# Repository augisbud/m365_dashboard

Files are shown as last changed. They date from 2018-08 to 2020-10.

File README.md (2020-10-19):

# Xiaomi M365 Display [This project is no longer maintained, because I don't have a platform to test it.]

I will be pushing pull requests, if you improve this in any way possible feel free to create a push request.



# Products Used  
Arduino Pro Mini    
I2C OLED 0.96" or 1.3" Screen
FTD1232 Usb Programmer   
3d Printed Bracket  
1N4148 Diode  
0.25w 120ohm Resistor       

Estimated price is around 20$ (Inluding Printed Parts).

Knowing the price is around 20$ you can get the Xiaomi M365 Pro top panel from aliexpress for around the same price and a better look, unless you need additional features just go for the pro display.

# Flashing  
  
Please install the libraries I provided in the files, install them to you arduino library folder, usually              
  C:\Users\\%username%\Documents\Arduino\libraries  
I'd recommend you to use Arduino 1.6.6  
https://www.arduino.cc/en/Main/OldSoftwareReleases  

# Physical Connections  
  

# Updating M365 firmware / Disabling the Dashboard
Turn on the scooter and immediately engage and hold the throttle and brake before the logo disappears from the dashboard LCD. You will enter on dashboard disabled mode.
The Arduino TX/RX pins will go to hi impedance state leaving the communication BUS free.

By this way you can update de M365 firmware without disconnecting the dashboard or any cable.

A new power cycle will reset the dashboard to normal mode.

# Known Issues  
Sometimes the Arduino Freezes, a watchdog is in place but doesn't always trigger.  

# Screen caps
# Soldering, soldered directly to the cable coming from the MCU
5V To Red    
GND To Black  
BUS To Yellow  
  
A video on how everything is soldered may come soon.

Meanwhile you can enable subtitles in English in this YouTube video produced in Spanish language
https://www.youtube.com/watch?v=JQUNXCyj2Fs

# UI
UI pictures from version 0.2  
  
  

More pictures are coming soon.

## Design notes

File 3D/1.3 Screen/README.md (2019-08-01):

This is some CAD files for the 1.3" screen insted of the 0.96" one.

# Note:
You need to cut off one side where you put in the actual screen to fit it in

I haven't had time to fix this but feel free to DIY!

The 1.3" screen seems like it not SSD and so has a white line on the left and some letters can be consmed by the left side like [this](https://i.imgur.com/5XdflrQ.jpg) so I've added a language.h filt that *kinda* works but still kinda jank.

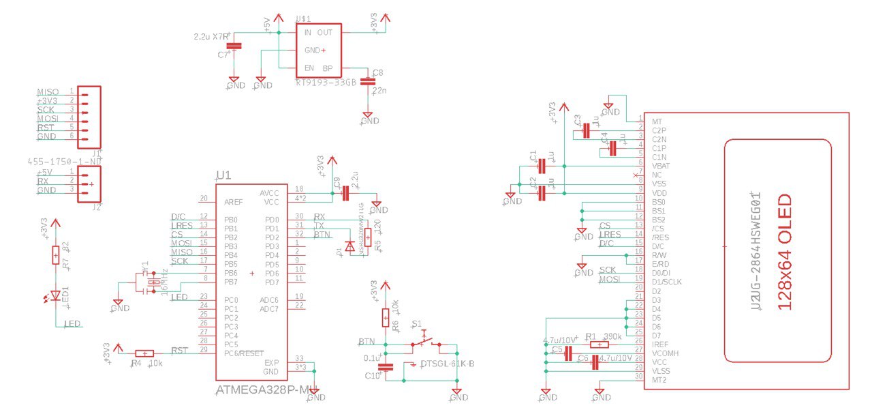
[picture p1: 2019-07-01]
circuit/v1_working.png

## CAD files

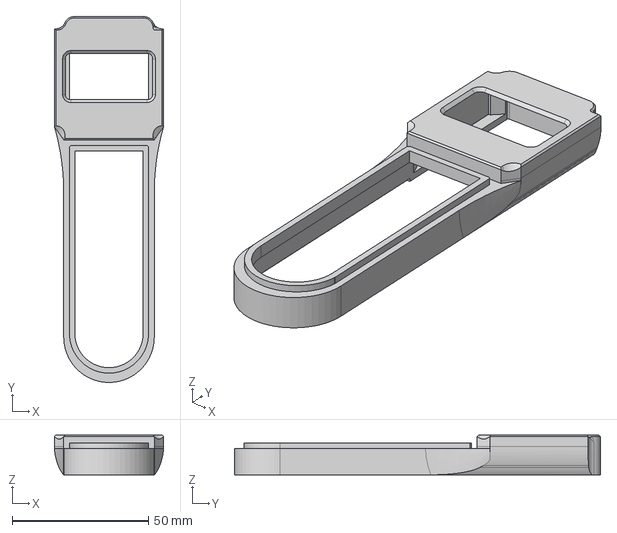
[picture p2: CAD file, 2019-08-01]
3D/1.3 Screen/case_v4_1.3-screen.step
40.0 x 134.1 x 14.6 mm

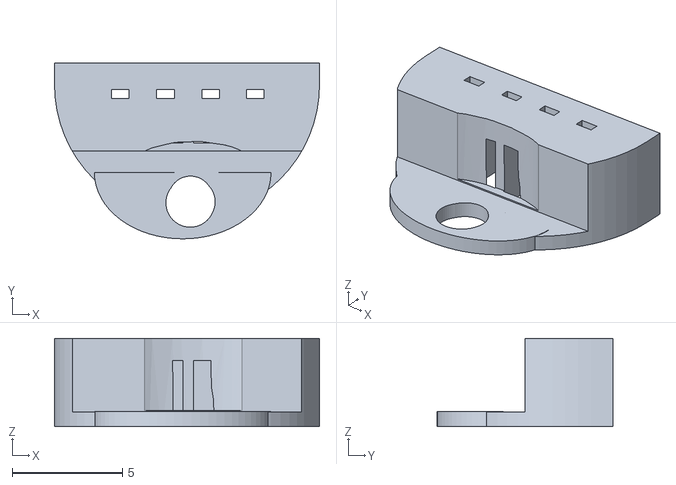
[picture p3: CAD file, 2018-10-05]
3D/Connector-edited.stl
12.0 x 7.96 x 4.00

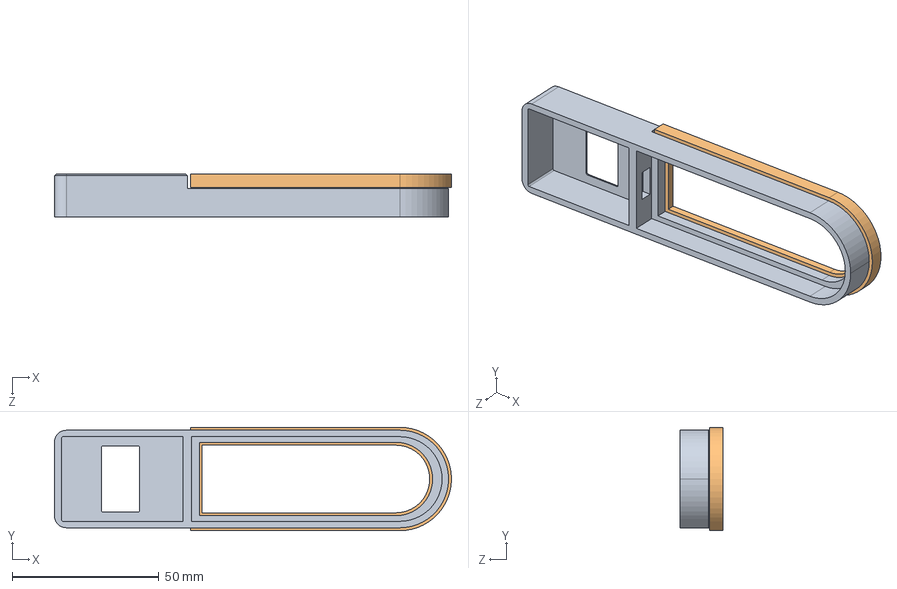
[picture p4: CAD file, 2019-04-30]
3D/newCase/STEP/case_v3.STEP
135.1 x 35.2 x 14.6 mm

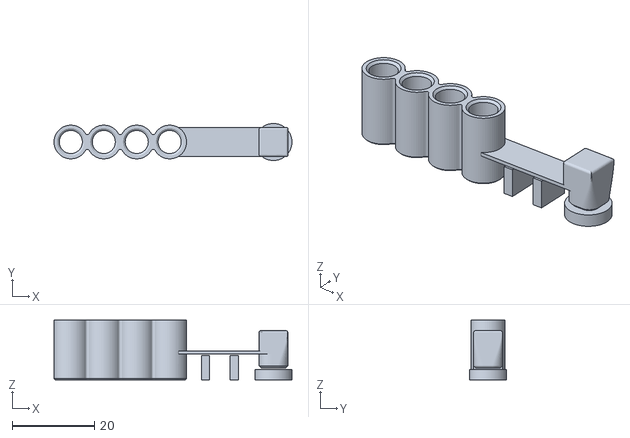
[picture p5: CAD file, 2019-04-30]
3D/newCase/STL/leds_v3_selfSupported.STL
57.8 x 9.00 x 14.4

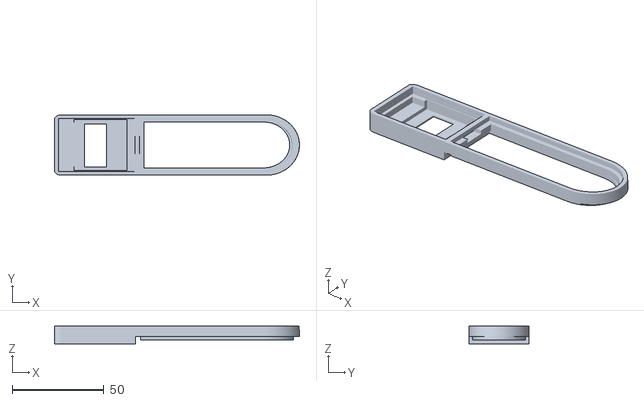
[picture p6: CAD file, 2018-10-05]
3D/Bracket-edited.stl
133.7 x 33.0 x 9.65

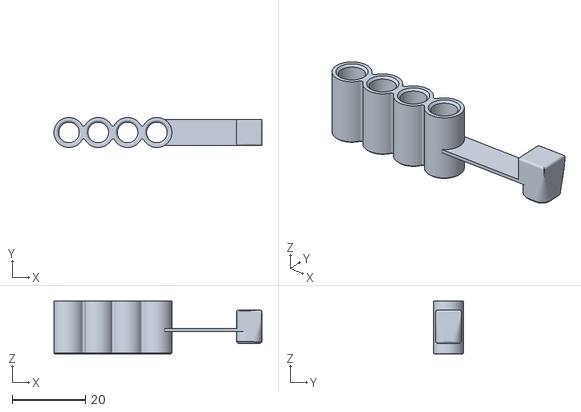
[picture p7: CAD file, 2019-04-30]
3D/newCase/STL/leds_v3_noSupports.STL
56.8 x 8.19 x 14.4

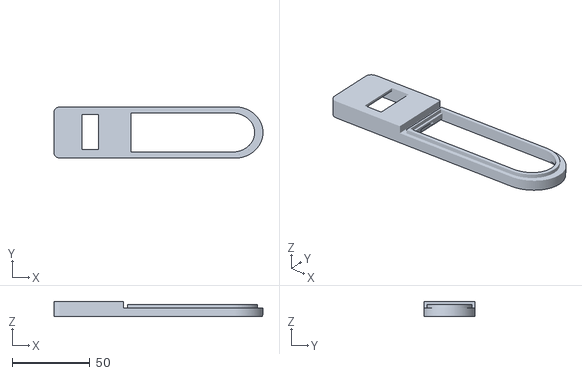
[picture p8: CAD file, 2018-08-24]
3D/Bracket.stl
134.1 x 33.0 x 9.64

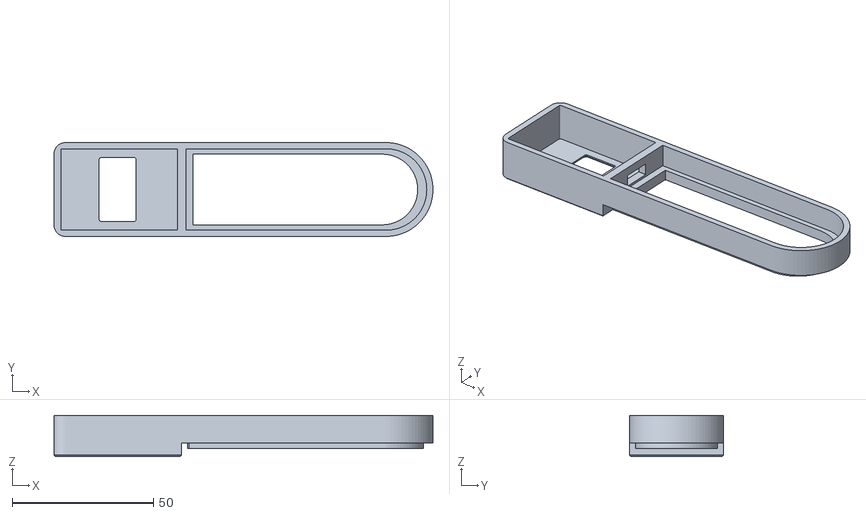
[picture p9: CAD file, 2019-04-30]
3D/newCase/STL/case_v3_noSupports.STL
134.1 x 33.2 x 14.6

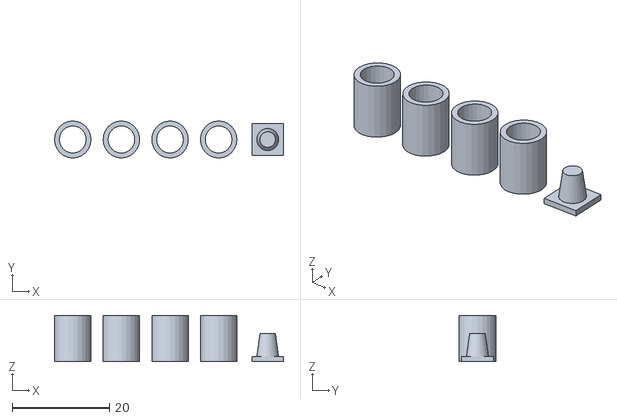
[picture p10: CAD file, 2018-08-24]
3D/LEDS & Button Extender.stl
47.1 x 7.63 x 9.50

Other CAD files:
3D/newCase/STEP/leds_v3.STEP
3D/newCase/STL/case_v3_selfSupported.STL
3D/1.3 Screen/case_v4_1.3-screen.f3d
3D/1.3 Screen/case_v4_1.3-screen.stl
3D/Custom top panel.f3d
3D/M365_panel_windowed.f3d
3D/newCase/SLDPRT/case_v3.SLDPRT
3D/newCase/SLDPRT/leds_v3.SLDPRT

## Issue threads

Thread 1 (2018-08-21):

Hello Kate - no Bus-

McKaNaN, 2018-08-21:
Hi.

I installed it and all done! :)

The problem, when I power on M365: LCD shows this message: "Hello Kate - no Bus -"
Any idea?

McKaNaN, 2018-08-21:
https://youtu.be/q8CMcGD0eyE

augisbud, 2018-08-24:
Have you used the schematics provided?
https://camo.githubusercontent.com/a912641249173768ae60670e843c62294d06da4f/68747470733a2f2f656c656374726f2e636c75622f646174612f666f72756d2f6d657373616765732f3432363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

augisbud, 2018-08-24:
Gonna upload an updated version :)

augisbud, 2018-08-24:
Check out the new code provided, it's a revision from the original one, better ui and stability, however the arduino freezes once in a while, a watchdog seems to help it but not all the time, still looking for a solution 😕

McKaNaN, 2018-08-24:
Ok! I check it and comment here :)

McKaNaN, 2018-08-27:
I compiled new code and show this:

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

A friend say me that the connection is:
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

Its correct?

augisbud, 2018-08-27:
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

augisbud, 2018-08-27:
I use this exact scheme without a problem

augisbud, 2018-08-27:
Send me a picture of the top part of your scooter with the pcb

McKaNaN, 2018-08-27:
Nothing. I cant connect BUS with screen.
All time shows same message: "BUS not connected! No data to display!"

I have question:
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

This pins are correct?

augisbud, 2018-08-27:
Yes the pins are correct, can you unscrew the pcb and send me a pic

McKaNaN, 2018-08-27:
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

Connections are same at schematics :)

augisbud, 2018-08-27:
I meant the scooter's pcb

augisbud, 2018-08-27:
The blue one with the button

augisbud, 2018-08-27:
Ok, I'm going to flash the firmware to my scooter to make sure it's ok

McKaNaN, 2018-08-27:
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

I used this connection picture. I think that is the same that you but I cant understand where is the problem :(

augisbud, 2018-08-27:
Me neither, are those really 1n4148 diode, 120 resistor?

McKaNaN, 2018-08-27:
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
This is the resistor

Diode shows:
PH
41
48

Is correct?

augisbud, 2018-08-27:
You might wanna try a 1n4148 diode although they seem to be very similar

McKaNaN, 2018-08-27:
I dont know....
I need to go to buy new diode.
I change + and - of diode, and shows same message :(

OMG

chriskross, 2018-09-01:
Have you connect the same gnd for arduino and pcb?

McKaNaN, 2018-09-01:
Yes! The GND of Bluetooth PCB in GND of Arduino Mini Pro

Closed 2018-09-14.

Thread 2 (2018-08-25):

M365 languages translation

AntoineWaes, 2018-08-25:
Hey ! I can provide you my language.h file in French if you want to add it to the files ;)
Maybe you could do a video showing how to plug and solder the wires

Thanks for the sharing, and nice work dude !

AntoineWaes, 2018-08-25:
Thanks a lot for the screens ! The wiring doesn't seems to work for me, it keeps saying 'No bus connected" .. And the M365 shows the 4 LEDS on (with one green)...

augisbud, 2018-08-25:
Have you connected the resistors and the diode
?

AntoineWaes, 2018-08-25:
Yes, this is what I did, is it OK ?
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

augisbud, 2018-08-25:
No let me get a piece of paper quick

AntoineWaes, 2018-08-25:
Thanks

augisbud, 2018-08-25:
https://photos.app.goo.gl/1Zbvogu9Ag9gwViG6

AntoineWaes, 2018-08-25:
This is mine : still not working, and this is what you sent .. What firmware do you have ?
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

augisbud, 2018-08-25:
1.4.0, do they have a common ground? I.E The ground and vcc of the arduino is soldered to the scooter

AntoineWaes, 2018-08-25:
Yeah they are both connected to the  Arduino from the scooter

augisbud, 2018-08-25:
Hmmm, ok, what chip is that?
https://i.imgur.com/VHPWohZ.png Here's how to connect it

AntoineWaes, 2018-08-25:
Do you know if there is a difference btw T4148 and 1N4148 diode ? Because I have a T4148

augisbud, 2018-08-25:
It might be the case, no, not really

augisbud, 2018-08-25:
I think that's something to do with the arduino not sure yet

AntoineWaes, 2018-08-25:
The resistor is a 120ohm right ?

augisbud, 2018-08-25:
Yes

AntoineWaes, 2018-08-25:
I try a different Arduino, now it is a Arduino Nano. Can you provide a picture of your installation ? With the Arduino ? It still doesn't work .. I'm pretty much desperated right now

augisbud, 2018-08-25:
Use the 1N4148 Diode, and the schematics provided in the wiki

augisbud, 2018-08-25:
I'm not home rn so I can't help

augisbud, 2018-08-26:
This is what I found browsing russian forums about your issue
---Russian Forums---
In general, I realized the problem with nano. CH340, which stands in them, does not fall into any sleep mode, but constantly pulls TX to plus through a 1kΩ resistor. Accordingly, the bus levels are shifted upwards and the scooter ceases to perceive them.

Closed 2018-08-29.

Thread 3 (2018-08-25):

Freezes once in a while

augisbud, 2018-08-25:
The Arduino freezes once in awhile it only seems to be happening with my hard driving so right now I think it's trying to open the menu because there is no speed check for that but that doesn't always seem to be the case. Anyone else experienced something similar?

augisbud, 2018-08-26:
I'm starting to think that the issue is with the library, gonna change it to the Adafruit library and maybe create a separate github for testing purposes 😕

augisbud, 2018-09-05:
Try out [this](https://github.com/augisbud/m365_dashboard/tree/beta)
This is the beta branch, it might contain bugs, but worth checking out, it uses a U8G2 library so download it before.

augisbud, 2018-09-10:
Well I have discovered that it seems like the bus overflows, because everytime i spin the tire in the air from 5km/h to 30km/h(custom firmware), the speedo freezes and sometimes catches back on

tibzejoker, 2018-09-10:
Oh, ok..
So maybe the solution may be to add an interruption timer that starts before every serial.read ?
Then you can flush the serial port if it freezes by doing something like that if i remember :
void flushSerial(){
  while(Serial.available () > 0){
     Serial.read();
  }
}

tibzejoker, 2018-09-10:
Or, maybe the best solution is to use
Serial.onReceive(stockInATabFunction);
that triggers on every serial event ?
then in the dataFSM(), you can just check if there is something waiting in the tab

augisbud, 2018-09-10:
Hmmm, It freezes because it receives too much data so a millis() delay could help it

augisbud, 2018-09-10:
But a delay is not a solution, so having something like you mentioned could work better

voodou59, 2018-10-07:
Did you tried with pro mini 3.3v ?

tibzejoker, 2018-10-08:
I have no idea, but can you give us the link to that video please ?
i've also seen that some days, instead of freezing, it could work just nicely.. Btw, how have you found out that it is an overflow error ?
Thanks !

augisbud, 2018-10-10:
It's kinda an overflow, even the xiaomi mi app freezes if you put the scooter in the air and press the throttle fully

augisbud, 2018-10-10:
> Hi, thanks for sharing that project. Did you tried with pro mini 3.3v ?

You will destroy it, the rail is 5v, a capacitor or some kind of regulator.

voodou59, 2018-10-10:
Not really. It is supposed to accept voltage up to 12VDC.

voodou59, 2018-10-10:
I agree that 12v requires a heatsink but the electric scooter regulator range is 0 to 5.5-6v max

jordicli, 2018-10-11:
For me it's freezing in every trip :(

lukaszlukasz0, 2018-10-11:
For me it happend one time, i drive with this software over a week (60km).
Maybe it depends of arduino, ther are so many manufactors?

augisbud, 2018-10-11:
more like on the scooter I guess

tibzejoker, 2018-10-11:
Mine freezes every 1km approximatively..
I dont really know why because when i put the scooter in the air and press the throttle fully nothing more than the "normal" 1km freeze occurs..
I'm trying to add a second "watchdog arduino" to see if i can fix it that way

tibzejoker, 2018-10-11:
of course i have deleted the bootup par to skip the animation ^^.
I'll tell you if it can kind of fix it

augisbud, 2018-10-11:
Check if the percentage drops after sometime, because sometimes only the speedo freezes

tibzejoker, 2018-10-11:
no it doesnt unfortunately.. everything stops even the percentage.. (infinite power i gess ?? 👍 )

augisbud, 2018-10-11:
hmm, for me only the speedometer crashes

lukaszlukasz0, 2018-10-11:
and for me :-)

All scooter hang up, and stop driving, all led are off, and the display was on and suspended showed the speed.

tibzejoker, 2018-10-11:
hey guys i've figured out that when the port crashes, the arduino is still alive and working !
https://photos.app.goo.gl/jfD18F17mBE4PSTo9
On this video you can see that the screen is frozen and the arduino is still working (i've made the led on port 13 blink for debug)

lukaszlukasz0, 2018-10-11:
I see something like this sometimes (long time ago), when i drive with phone on bluetooth, my speed on mihome app freezes.
 I am not sure if this is not a coincidence, but often helped by tapping on a platform or passing through bumps or holes on the way :smiley:

tibzejoker, 2018-10-12:
I've finally fixed it with my second watchdog arduino.
Actually, when the arduino freezes due to a serial overflow, the 13th pin starts to blink pretty fast, and you cant reset it via the reset pin. You have to physically turn it off and on.
That's why i'm now doing that.
I'll release my fix tomorrow i think, it only costs the price of a second arduino nano.
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

tibzejoker, 2018-10-13:
It's not the best solution but  at least.. it works ^^
https://github.com/tibzejoker/m365_dashboard

carlosmellado, 2018-10-14:
Hi all,
I’m waiting for a new oled screen to test it out since I broke mine :p but...
There is a command for serial that checks for an overflow, and another for flush the serial, so... what if you put this piece of code at the very begging of the loop() function?

if(XIAOMI_PORT.overflow()) {
XIAOMI_PORT.flush();
}

Sorry if there are errors but I’m writing from the phone.
Will be working also to find a software based solution! :)

augisbud, 2018-10-14:
XIAOMI_PORT.overflow() doesn't really exist so we would need to define it.
XIAOMI_PORT.flush is the same as Serial.flush() so it could work.

augisbud, 2018-10-14:
https://www.arduino.cc/en/Reference/SoftwareSerialOverflow

toniht88, 2018-10-14:
> of course i have deleted the bootup part to skip the animation ^^.
how did you do it??

augisbud, 2018-10-14:
> > of course i have deleted the bootup part to skip the animation ^^.
> > how did you do it??

  display.setFont(m365);
  displayClear(0, true);
  display.setCursor(0, 0);
  display.print((char)0x20);

remove this.

vanekCZ, 2018-10-17:
Hello, just upload everything to arduin and everything will work? Or does something have to be fine-tuned? Can I translate the language somehow? I needed a Czech language. Thanks for advice.

carlosmellado, 2018-10-17:
> Hello, just upload everything to arduino and everything will work? Or does something have to be fine-tuned? Can I translate the language somehow? I needed a Czech language. Thanks for advice.

Please, keep this thread for the issue related.

vanekCZ, 2018-10-17:
> > Hello, just upload everything to arduino and everything will work? Or does something have to be fine-tuned? Can I translate the language somehow? I needed a Czech language. Thanks for advice.
>
> Please, keep this thread for the issue related.

Better would be if you answered, then I will delete it.

jordicli, 2018-10-17:
> if(XIAOMI_PORT.overflow()) {
>XIAOMI_PORT.flush();
>}

It seems that overflow function it's defined in serial software library and not defined in serial hardware library so can't be used in our case :(

I found this topic [https://arduino.stackexchange.com/questions/19078/hardwareserial-check-for-overflow/19085](https://arduino.stackexchange.com/questions/19078/hardwareserial-check-for-overflow/19085) don't know if it can be useful

lukaszlukasz0, 2018-10-18:
I have idea, but i can't test it, because my display dont hang up ( i cant do fast that 30km/h on my engine)

Check 172 line of define.h
Speed can't be integer, because integer is to max 32,768 (32,7km/h).
It has to be unsigned int or long.

Test if that helps?

augisbud, 2018-10-18:
I will test it

augisbud, 2018-10-18:
Whenever it's unsigned int there are random speeds shwon

lukaszlukasz0, 2018-10-18:
Something like that happens with Arduino as we cross the variable barrier https://imgur.com/gallery/r9HgHd5

lukaszlukasz0, 2018-10-19:
I think that you could use our usb-to-ttl and see what happens on the line BUS? When this bug is happening.

Unfortunately, I do not have such possibilities because my scooter does not accelerate to this speed, but I will try to work with the Botox Software generator and set other parameters :wink:

jordicli, 2018-10-19:
In my case the freezing has nothing to do with going faster than 30 km/h, I'm on stock firmware 1.4.0 and can't go faster than 25 km/h

nebman, 2018-10-19:
Check your connections too. I've had the display freezing because of vibrations when testing with dupont connectors

lukaszlukasz0, 2018-10-24:
i make test code to calculate speed over 32.7, maybe this will help the screen not freezing.
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
dimitrisdaniil, 2019-09-13:
Has anybody found a solution for the freezing, without second arduino as watchdog?

zazzimazzi, 2019-09-19:
Hi can you converting  this project        SSD1306AsciiWire   library    to   adafruitssd1306.h library   or  u8glib  or  u8g2lib

dimitrisdaniil, 2019-09-19:
To be honest personally i do not have the knowledge to do it... It requires a lot of reading...and i do not have the time, this reriod...
But why you want to do this? It works pretty well this way

dimitrisdaniil, 2019-10-17:
Is this project abandoned?

GivvHub, 2019-10-18:
i thikk: yes. not happy

alexandrugai, 2019-10-30:
anyone tried this project on a d1mini?

pawelmakowski26, 2020-03-24:
Witajcie.
Wyeliminowałem zawieszanie się dodając rezystor 120ohm na linii data pomiędzy płytka m365 a Arduino.
Do tej pory zawieszała się co chwilę , oraz silnik czasami jakby się wyłączał . Dzisiaj rano przejechałem 5 km bez żadnego błędu.

pawelmakowski26, 2020-03-24:
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

Na razie nie zawiesza sie

duts33, 2020-03-24:
> Witajcie.
> Wyeliminowałem zawieszanie się dodając rezystor 120ohm na linii data pomiędzy płytka m365 a Arduino.
> Do tej pory zawieszała się co chwilę , oraz silnik czasami jakby się wyłączał . Dzisiaj rano przejechałem 5 km bez żadnego błędu.

Have you also had the screen freeze on the speed reading?

pawelmakowski26, 2020-03-24:
Today i driver

duts33, 2020-03-24:
> today I drove about 15km and the meter worked perfectly. never hung.

thanks, I will try this method too.

pawelmakowski26, 2020-03-25:
Wczoraj działało idealnie. Dzisiaj znowu przerywa.

VVerlog, 2020-06-09:
Hi together, is there any solution available till now?

duts33, 2020-06-09:
There is no concrete solution. I replaced the resistors with other values, as advised in similar projects, and the Arduino still freezes. It can run for a few days without freezes, and then still hang.

VVerlog, 2020-06-09:
Has anyone a look at the data signal with an oszi? Maybe the signal is not good enough. But I think there is an code bug too, because freezing should not happen if the data could not be read. Maybe something with interrupt. Now I will start to have a look on the code.

hojnikb, 2020-10-06:
Any solutions for this till now?

38293312, 2021-04-02:
I can’t turn on the headlights with this item meter. I wonder if everyone has the same problem?

duts33, 2021-11-15:
> Glad to release the v 0.B version (B means Bruno). A improved software watchdog is in place. Never freezed in some months of heavy use, at high speed and neither on hard braking. Made the necessary corrections to made the code work on pro's version (now can display current speed, or real time current value) cause these models, unlike the classic m365, have another ble protocol. No more crashing when tyre is spinning. Works fine on almost every 5V Arduino board, even all those who integrate a Serial TTL that could interferes with bus, Half Duplex is now reached by SoftwareSerial(). Tested on Xiaomi Scooter Essential, Xiaomi PRO 2 and Mi Scooter 3. Also works in combination with CamiBLE 075 v 10. You can find the project on my Github home.

Could you give a link?

Dubstaaa, 2021-11-18:
Im hard working to make it cheaper, easier and more affordable... even more useful than commercial version of “M365 dash”. To achieve a good result I need some more days to refine my project.
Next week two versions will be released :
Ninebot compatible;
Xiaomi compatible;

Dubstaaa, 2021-11-25:
Im glad to share with you my project, fully compatible with multiple scooter versions.
Neat dash, test release by Bruno. Available on https://github.com/Dubstaaa/NeatDash-

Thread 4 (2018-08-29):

Battery Warning issue

AntoineWaes, 2018-08-29:
Hey,
I finally got the answer for my last issue with the Arduino Nano. Turns out that the baud rate of the M365 is 115200, and only the mini pro has the same. This means that nano won’t work

I have another issue now : this screen keeps showing every seconds, and I have no idea what it means, and why it’s there for
Can you help me ?

AntoineWaes, 2018-08-29:
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

augisbud, 2018-08-29:
Go into settings full brake + full gas, and select battery warning limit

augisbud, 2018-08-29:
Use brake to surf the menu, and gas to select

AntoineWaes, 2018-08-29:
Nice ! Thanks a lot

Closed 2018-08-29.

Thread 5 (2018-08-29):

Battery Warn

alexrs98, 2018-08-29:
Hi. I would like to know in what percent of battery the warning begins to appear.
How can you change it so that the warning comes out when you have less than 20% left? With 35% the warning comes out and it's a bit annoying.
Thank you

augisbud, 2018-08-29:
Go into the menu, FULL BRAKE + FULL GAS, and selected the warning limit

Closed 2018-08-29.

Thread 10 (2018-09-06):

Verify error

McKaNaN, 2018-09-06:
Hi!

This new version (2.0) shows error at verify in Arduino:

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

Any solution?

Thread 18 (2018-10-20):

'WheelSize' was not declared in this scope

serpro, 2018-10-20:
When I try to verify the code in Arduino I get that message on this line:
https://github.com/augisbud/m365_dashboard/blob/master/M365/M365.ino#L419

augisbud, 2018-10-21:
It's fixed redownload the source

Closed 2018-10-21.

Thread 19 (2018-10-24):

How to connect the arduino without soldering into m365 pcb?

carlosmellado, 2018-10-24:
Hi guys,
I know this is not an issue, but I don't know where to write it, so, feel free to move it or whatever if you want.

I saw that there is a "connector" 3D model on 3D folder, but... What kind of connectors goes in?
I mean, what should we do with this 3D piece? I would like to implement this in my scooter but it would be nice if I didn't have to solder nothing directly on the board.

Any help would be appreciated!

pikselq, 2018-10-25:
Hi,
Look at last photo
https://www.ebay.co.uk/itm/OSD-Data-Display-for-Xiaomi-Mijia-M365-Screen-0-96-Dashboard-Waterproof-IPX2-/263945593704

Closed 2018-10-29.

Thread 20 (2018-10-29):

Scooter brakes itself every 3-4 seconds

carlosmellado, 2018-10-29:
Hello again,
I downloaded the last code and installed the arduino today, and the speedometer doesn't update, per instance, it shows 6.0Km/h and it keeps frozen until I break and run again, showing another number that it doesn't corresponds with my current speed.

Also, and the worst, the scooter breaks using the motor, every 3-4 seconds, maybe more, but it's doing driving impossible...

Any suggestions?

augisbud, 2018-10-29:
use an older version

augisbud, 2018-10-29:
https://github.com/augisbud/m365_dashboard/tree/fe808eb38dab5e830124fd2576c1aa4a17ca16ec

augisbud, 2018-10-29:
Check the new source.

carlosmellado, 2018-10-29:
Tested and it's working fine now.

But you have a syntax error on your last commit at line 244, you have to remove the last parenthesis:

```
//m365_info.sph = abs(S23CB0.speed) / 1000L); // speed (BAD)
m365_info.sph = abs(S23CB0.speed) / 1000L; // speed (GOOD)
```

Thanks a lot!

augisbud, 2018-10-29:
thank you too, let me know if it freezes

carlosmellado, 2018-10-30:
Hi there,
I confirm that it's still freezing. Yesterday I tested it 5 minutes and no freezes ocurred.
But today, I did 10km and on every first gas, the speedometer freezes. Sometimes the watchdog works, others not. I restarted my scooter with the same luck. Frozen on the first gas :(

augisbud, 2018-10-30:
Does your code contain this?
```
  // CURRENT SPEED CALCULATE ALGORYTHM
  if (S23CB0.speed < -10000) {// If speed if more than 32.767 km/h (32767)
    c_speed = S23CB0.speed + 32768 + 32767; // calculate speed over 32.767 (hex 0x8000 and above) add 32768 and 32767 to conver to unsigned int
  } else {
    c_speed = abs(S23CB0.speed); }; //always + speed, even drive backwards ;)
```

carlosmellado, 2018-10-30:
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

Yes, I pulled the code yesterday, and this piece of code seems to be pushed 2 days ago.

augisbud, 2018-10-30:
` long _speed;
  unsigned long c_speed; //current speed`

can you try this?

carlosmellado, 2018-10-30:
> ` long _speed; unsigned long c_speed; //current speed`
>
> can you try this?

I will try when I can. I have the arduino hidden on the chassis and I have to unmount the chassis in order to have access to it.

augisbud, 2018-10-30:
me too :(

lukaszlukasz0, 2018-10-30:
I corrected the variables to "long" and changed assignments (unsigned long).
Check pull request :)

augisbud, 2018-10-30:
pulled

carlosmellado, 2018-11-06:
I pulled the last version and the scooter doesn't brake like before, at least, it seems to work well in my last 3 trips (10 km each one). The speedometer just froze once.

But... I don't know if it's a coincidence, but yesterday, when I powered on the front light, the scooter started braking a lot of times per second on the motor... A soft brakes but you could felt them...

I had to restart the scooter and continue driving without light.

Today I will try again to see if it reproduces again.

carlosmellado, 2018-11-06:
> You need to replace F2 fuse, on the motherboard.

Why? 🤔

lukaszlukasz0, 2018-11-06:
Because its broken 😁

you describe a light defect that is directly related to the damage of this fuse.

carlosmellado, 2018-11-06:
Well, will try again today and I will tell you later 😄

Thanks!

lukaszlukasz0, 2018-11-06:
This help
http://imgur.com/gallery/Yirukc9

This is self resetting Fuse, need to be 500mA

carlosmellado, 2018-11-21:
Somebody knows the fuse characteristics?

Is this one valid?
[Ebay Link](https://www.ebay.es/itm/5-X-1206L050YR-Fuse-PTC-polymer-500mA-1206L/112699733600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)

Closed 2018-10-29.

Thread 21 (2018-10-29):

Compilation Issue

nowisnowis, 2018-10-29:
Hi when trying to compile and uplode your code I get the following errors:

Arduino: 1.6.6 (Windows 10), Board: "Arduino Pro or Pro Mini, ATmega328 (5V, 16 MHz)"

C:\Users\svillalobos\Documents\Arduino\sketch_oct29a\M365.ino: In function 'void setup()':

M365:20: error: redefinition of 'void setup()'

 void setup() {

      ^

sketch_oct29a:10: error: 'void setup()' previously defined here

 void setup() {

      ^

C:\Users\svillalobos\Documents\Arduino\sketch_oct29a\M365.ino: In function 'void loop()':

M365:76: error: redefinition of 'void loop()'

 void loop() { //cycle time w\o data exchange ~8 us :)

      ^

sketch_oct29a:15: error: 'void loop()' previously defined here

 void loop() {

      ^

exit status 1
redefinition of 'void setup()'

  This report would have more information with
  "Show verbose output during compilation"
  enabled in File > Preferences.

Could you point me where can be the error

Thanks

Simon

augisbud, 2018-10-29:
Simply download the source, extract it to your desktop, open the M365 folder and then try to compile.

nowisnowis, 2018-10-29:
Thanks, that did it!, noob issue, just to let you know when you upload the libraries the sketch tab contains already a void setup and a void loop

Closed 2018-10-29.

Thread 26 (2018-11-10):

Rotate screen 180 degrees

serpro, 2018-11-10:
Hello

I have the dual colour screen "Yellow/Blue" and I noticed it would look much better if I had the yellow bar on the bottom rather than on the top. I can't see in the code any configuration for this.

Kind regards,
Sergio

carlosmellado, 2018-11-11:
This kind of screens doesn’t have any configuration for the color. The top LEDs are yellow and the other ones are blue, so, you can’t change them by software.

carlosmellado, 2018-11-11:
Or maybe you’re asking that in order to flip down manually your screen and then flip also the graphics on code 😅
On this case, you have to set this code on your setup, after initializing your display, before display.setFont(m365);

//Rotate the screen
display.setRotation(2);

I think the number 2 is the one you’re looking for, if not, try changing it!

Good luck!

LukCaha, 2018-11-11:
see this:
https://github.com/greiman/SSD1306Ascii/issues/23#issuecomment-396244537
and use this:
`display.displayRemap(true);`

serpro, 2018-11-11:
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

That worked! Thanks!

Closed 2018-11-11.

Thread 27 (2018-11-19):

Configuration to use SPI OLED

myoung34, 2018-11-19:
Do you have any examples on how to use an SPI OLED that has 7 pins (mostly RST)

Hermit12, 2019-02-17:
Hi, I'm new to programming and like to use a [1.3'](https://www.aliexpress.com/item/1-3-inch-IIC-I2C-Serial-128x64-OLED-LCD-Display-White-Screen-Module-For-Arduino/32830144222.html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) or [1.54'](https://www.aliexpress.com/item/1-54-inch-White-OLED-Display-Module-128x64-SPI-Interface-OLED-Screen-Board-3-3-5V/32837724627.html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,searchweb201602_6_10065_10068_10547_319_317_10548_10696_10084_453_10083_454_10618_10304_10307_10820_10821_537_10302_536_10902_10059_10884_10887_321_322_10103,searchweb201603_70,ppcSwitch_0&algo_expid=4d1234bb-d015-4664-b1a6-a95c27f7a033-0&algo_pvid=4d1234bb-d015-4664-b1a6-a95c27f7a033&transAbTest=ae803_4) Display instead of the 0.96' one.
The oleds I have in mind are hopefully compatible with SSD1306, I tested the 1.3' one and everything seems to work, but the whole content is set a little bit to the left. What do I have to change in your code to set it to the center?
Regards

augisbud, 2019-02-18:
@Hermit12  the resolution of your screen is bigger than 128x64, so you would need to adapt to that in the code, essentially shift everything or make everything bigger

Hermit12, 2019-02-18:
Thank you for your quick answer. I figured out that it will work if I modify the starting point 2 columns to the right, but I'm not quite sure how to do it. Resolution is the same but apparently all existing 128x64 OLEDs with SH1106 have the 128x64 OLED screen centered into the 132x64 display RAM, which leads to a two pixel shift, when using SSD1306 software. Have you any idea how to shift the starting point?

augisbud, 2019-02-19:
@Hermit12 you could try to change command like display.setCursor(0, 0); to display.setCursor(0+2, 0);

augisbud, 2019-02-19:
@myoung34 to use the SPI OLED, you would need to reconfigure the initialization, an example
SPI initialization:
https://github.com/greiman/SSD1306Ascii/blob/master/examples/HelloWorldSpi/HelloWorldSpi.ino
I2C initialization:
https://github.com/greiman/SSD1306Ascii/blob/master/examples/HelloWorldWire/HelloWorldWire.ino

Using these examples you could try to do it, I don't have a SPI screen so I can't test it

augisbud, 2019-02-19:
@myoung34 to use the SPI screen, go to defines.h and change
`//#define DISPLAY_SPI
#define DISPLAY_I2C`
to
`#define DISPLAY_SPI
//#define DISPLAY_I2C`

Hermit12, 2019-02-28:
Figured it out. If you want to use bigger screen with different chip (SH1106) you just have to edit display.begin:
`display.begin(&SH1106_128x64, 0x3C);`
or for SPI `display.begin(&SH1106_128x64, PIN_CS, PIN_DC, PIN_RST);`
The library you use supports it OOB.
Maybe you can add this code as enhancement in your readme. I tested it with the 1.3'' I linked above.

Closed 2019-02-19.

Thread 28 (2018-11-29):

Bus not connected! No data to display!

nextor11, 2018-11-29:
Hi! I'm always getting "Bus not connected! No data to display!".

I've read through the closed issues and found one named "Hello Kate - no Bus-" where the problem seemed to be the resistor that was used, so I tried using different resistor values, first 120 ohm, then 150, then 100, but I always get that message. I also tried multiple 1N4148 diods, but no luck.

I know that the signal coming from the BLE module reaches the RX pad, so I don't know what might be the problem.

Any suggestions would be much appreciated. Thanks!

piyu23srma, 2018-12-07:
Hi,
I am using Arduino Nano for testing. All the connection are completed as shown in the schematic. But I am getting the error "BUS not connected! No Data to display!"

ronnymo15, 2019-01-06:
I also have the Problem, that the display shows "BUS not connected! No Data to display!". I tried it with 130 ohm, 100 ohm and 100+10+10 ohm resistors cause I had no 120 ohm at home - but nothing worked :(

afonsos, 2019-01-29:
I almost gone crazy with this,but solved with a resistor of 1% tolerance,that made it work

mikl912, 2019-03-15:
Hi! Ihave the same issue.
I tried changing the resistor and diode but it didn't work.
I have an arduino copy: a wavegate pro mini.
Do you have an idea of what can cause the communication trouble?
Thanks

Closed 2019-02-18.

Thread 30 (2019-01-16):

No S25C31 data

FlexH, 2019-01-16:
Hi,

I'm using an Adafruit Pro Trinket and i've got a problem :
Connection to the M365 is OK beacause using https://github.com/fogbox/m365_display in PASSIVE_MODE I can view throttle and brake status.

But I don't have any data from the S25C31 (current, voltage, etc...). All is 0.

You are testing these values on line 61

> if ((S25C31.current == 0) && (S25C31.voltage == 0) && (S25C31.remainPercent == 0))

Do you have infos about this problem ?

Regards,

augisbud, 2019-02-18:
It may be that either the diode or the resistor aren't correct, the resistors should be 1% tolerance, atleast that's what works for most

Closed 2019-02-18.

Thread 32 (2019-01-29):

Cruise Control Kers tail light

afonsos, 2019-01-29:
Im trying to change cruise control to ON,default is off.Change to ON then update cruise.
It stays ON but after next boot it goes to OFF again.
Im on an october release is this ok on recent updates? I didnt uploaded new code yet because Im not sure if its solved now and its a pain to get to arduino :)
Thanks for your work pretty simple to build this dash and awesome features

augisbud, 2019-02-18:
It hasn't been patched yet, it will be

augisbud, 2019-02-19:
@afonsos I have patched it, give it a try

afonsos, 2019-02-19:
Thanks for the patch augisbud

Im getting this error compiling sketch

M365:235: error: conflicting declaration 'unsigned int c_speed'

   unsigned int c_speed; //current speed

                ^

M365:234: error: 'c_speed' has a previous declaration as 'long int c_speed'

   long c_speed; //current speed

        ^

exit status 1
conflicting declaration 'unsigned int c_speed'

augisbud, 2019-02-20:
give it a try @afonsos

augisbud, 2019-02-20:
for me it compiles, haven't uploaded it to the scooter

afonsos, 2019-04-10:
works as expected.
Thanks mate

Closed 2019-02-19.

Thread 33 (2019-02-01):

Question about the resistor

Synced21, 2019-02-01:
Can someone explain me the purpose of the resistor? Does the resistor not also block the data that is coming for the TX0 pin.

Thank your four your help guys.

Synced21, 2019-02-04:
For any interest:

The idle state of a serial line is HIGH. Transmission starts with a start-bit which is a LOW and ends with 1/1.5/2 stop-bits which are HIGH.

The diode and resistor prevent the corruption; the M365 can still pull the line LOW.

rediculum, 2020-09-27:
Does it need to be exactly 120Ohm? I only have 100 or 150Ohm as spare.

NetBUG, 2020-09-28:
Hi @rediculum , 100 Ohm works perfectly.

Closed 2019-02-04.

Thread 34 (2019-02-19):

Restarts on turning light on

marioinz, 2019-02-19:
Hi.
Mine dashboard keeps restarting (or turns of after a few restarts) when front light is turn on: https://youtu.be/BllbipDUYU8
My display is 4 wire SPI - this is only diffrence to your recomendations (i only changed defines and display initalization method).
What may case such behavior ?

lukaszlukasz0, 2019-02-19:
Check the fuse f2 on mainboard.

augisbud, 2019-02-19:
@marioinz as Lukas said, check the second fuse on the main board, and try to flash the i2c code to see if it's the issue

marioinz, 2019-02-19:
ok. thx I will go with f2 fuse inspection ang get back heare with results. thank for quick response!

marioinz, 2019-02-19:
ok guys you were right. it is f2 fuse issue - i also have engine disruptions when lights is on. current resistance of fuse is ~2ohms.
what replace can i apply ? will this fit: http://electropark.pl/smd/3717-bezpiecznik-polimerowy-500ma-1812.html ?
thanks in advance

augisbud, 2019-02-19:
@marioinz it's because the display is restarting, not sure what fuse you need

lukaszlukasz0, 2019-02-19:
@marioinz 500mA is ok. Like original..

marioinz, 2019-02-27:
thanks guys! fuse replaced and now everything works just perfect! i bought 3 sizes and 0805 fits perfectly. you can close issue. Best

Closed 2019-03-04.

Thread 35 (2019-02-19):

Anyone checked if he can write registers ?

Synced21, 2019-02-19:
I´m currently analysing this project.
In your defines.h I can find this:
const unsigned char _hc[]    PROGMEM = {0x04, 0x20, 0x03};
This probably should be the wrapper for writing. BUT you don’t use it once in your ino file?
How can you even Change KERS,… this should not be possible or am I missing something

Synced21, 2019-02-19:
Sry i got it now your are using the struct _cmd.... okay.....
you should perhaps delete the line with:

const unsigned char _hc[] PROGMEM = {0x04, 0x20, 0x03};

if you dont use it.

Closed 2019-02-20.

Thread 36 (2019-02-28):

Display battery with 13s

Hermit12, 2019-02-28:
Hi,
I made a custom battery pack with 13s, but I can only see cells from 0 to 9, the last 3 voltages are hidden. Is it possible to add a scroll function so that it shows the other cells, lets say, every 3-4 seconds?

Regards

augisbud, 2019-03-04:
The code is able to handle up to 15 cells
`struct __attribute__((packed))A25C40 {
  int c1; //cell1 /1000
  int c2; //cell2
  int c3; //etc.
  int c4;
  int c5;
  int c6;
  int c7;
  int c8;
  int c9;
  int c10;
  int c11;
  int c12;
  int c13;
  int c14;
  int c15;
} S25C40;`
Line 146 in defines.h

This is where we display the battery cells info
`int v;
  int * ptr;
  int * ptr2;
  ptr = (int*)&S25C40;
  ptr2 = ptr + 5;
  for (int i = 0; i < 5; i++) {
    display.setCursor(5, 2 + i);
    display.print(i);
    display.print(": ");
    v = *ptr / 1000;
    display.print(v);
    display.print('.');
    v = *ptr % 1000;
    if (v < 100) display.print('0');
    if (v < 10) display.print('0');
    display.print(v);
    display.print((const __FlashStringHelper *) l_v);

    display.setCursor(70, 2 + i);
    display.print(i + 5);
    display.print(": ");
    v = *ptr2 / 1000;
    display.print(v);
    display.print('.');
    v = *ptr2 % 1000;
    if (v < 100) display.print('0');
    if (v < 10) display.print('0');
    display.print(v);
    display.print((const __FlashStringHelper *) l_v);

    ptr++;
    ptr2++;
  }
`
Line 179 M365.ino

Closed 2019-05-07.

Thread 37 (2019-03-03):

Power button issues

bouhady, 2019-03-03:
After connecting and assembling, the display is working fine BUT power button :
1. Not Toggling torch .
2. Not Turning of the "economic mode" (green led is on)
3. trying to powering off has no long beep - just when release the power button the scooter turned off.

geirskogul, 2019-03-03:
You've blown fuse F2

bouhady, 2019-03-04:
But when disconnecting the arduino the scooter works just fine?

bouhady, 2019-03-04:
> You've blown fuse F2

But when disconnecting the arduino the scooter works just fine?
The travel is ok and just when connecting the RX line the power button is not functioning.
If the Fuse was blown the problem was supposed to stay?

augisbud, 2019-03-04:
You may have shorted something

augisbud, 2019-03-04:
#34

bouhady, 2019-03-04:
OK. I'll try to replace this fuse and report.

geirskogul, 2019-03-11:
Also, make sure you're using a genuine nano or pro mini with the FTDI chips.  The MH348 chips don't pull up the signal properly and crash communications.

bouhady, 2019-03-11:
I used this Chip :
https://m.aliexpress.com/item/591964167.html
Do you think this was the problem?
(How should I pull up the RX well in that case?)

geirskogul, 2019-03-11:
Pulling up rx doesn't work unfortunately.

On Mon, Mar 11, 2019, 11:23 Yaniv Bouhadana <notifications@github.com>
wrote:

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

geirskogul, 2019-03-11:
That has the CH340, you need a genuine FTDI or an FTDI clone. When you
connect that one, does a red led start flashing on the dash? That's it
crashing

On Mon, Mar 11, 2019, 11:23 Yaniv Bouhadana <notifications@github.com>
wrote:

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

uvegp, 2019-04-14:
I've got the same issue (connected everything together, power button doesn't work, all 4 LEDs are glowing), but have not checked my fuses. I used an Arduino Nano clone from Aliexpress, had to remove the resistior from the original blueprint to get the data wire working. My workaround for the light issue was to add a switch to the circuit: first I power on the scoother, wait 5-6 seconds, then I power on the Arduino/OLED display circuit. This way I can turn the headlight on and I get the battery level displayed through the LEDs as well. Do you think I should still replace the F2 fuse? I mean if the setup is working this way, can I do damage to my scooter?

augisbud, 2019-05-07:
@uvegp you should probably still replace the fuse, for long term usage

Closed 2019-05-07.

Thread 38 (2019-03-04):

Possibility to add support for Ninebot ES1 / ES2?

NicholasTracy, 2019-03-04:
Hello,
 I have a ninebot ES1 that I have been playing with. I have tools available to reverse engineer the dashboard on the ES1 as well such as a scope with serial decoding and numerous Arduino Nanos and Minis.

Since both the M365 and the ES1 have the same connector to the dashboard and very similar design, does anyone know if its possible to use the same code to mod the ES1 or if it would be worth snooping the databus on the ES1 to see what is comming across? I'm actually very interested in taking it further and fully controlling the scooter with an arduino including throttle and brake commands and lighting as well as power and the alarm.

The dashboard is labeled G(black) T(yellow) P(green) 5(red) and I am assuming that G and 5 are ground and +5v. Not sure about the T and the P but I assume one is data bus and the other is the 36v power from the batter for the fuel gauge.

Any input is appreciated before I attempt anything further.

augisbud, 2019-03-04:
From what I know, the ES1 / ES2 / ES4 have a different way of communication, just like the m365 pro

augisbud, 2019-03-04:
You could try, and what you will see from the start are the brake and throttle values, others you need to request for.

NicholasTracy, 2019-03-04:
Awesome, thanks. I will look at it at some point and see whats available.

Closed 2019-04-30.

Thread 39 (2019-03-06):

MPH and US Degrees Version?

pilotdeveloper, 2019-03-06:
Happen to have a US Version with MPH and Degrees F?

augisbud, 2019-03-07:
If you want to do it yourself you just need to convert the values like speed, distance, temperature to us versions, i will start working on it

augisbud, 2019-03-07:
sph & spl = are speed values, just convert both of them to mph from kmh
milh & mill = are distance values, just convert both of them to miles from kilometres
temp = is the temperature value, just convert it to farenheit

pilotdeveloper, 2019-03-07:
Yes - I figured it out :)
I *may* do a PR to include it as a localization option for you if that's
cool!

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

augisbud, 2019-03-07:
should work, give it a try

augisbud, 2019-03-07:
make sure you uncomment line 7 in defines.h

Closed 2019-03-12.

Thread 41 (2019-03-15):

Hibernate feature

maniakpl, 2019-03-15:
Hi guys,
Wanted to add hibernate option to my dashboard. The dashboard must be unpluged from the scooter when changing or updating scooter's firmware, so hibernate option would be perfect for that.
Since I am new to programming, I need your help with this.
What lines of code should I put and where to get this feature?
Regards,
Bartek

augisbud, 2019-03-15:
i just have a toggle switch for the power of the arduino, not bothering with another menu option, although all you need to do is disable the packet request to accomplish this

afonsos, 2019-04-10:
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

villamany, 2019-04-29:
This will do the job https://github.com/augisbud/m365_dashboard/pull/50

Closed 2019-04-04.

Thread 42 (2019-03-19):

How to change language?

LukCaha, 2019-03-19:
Please, how to change language? When I edit language.h to something like that:
```
//#define Language ENG //English
#define Language FRA //French
//#define Language RU //Russian, use together with the russian font in libraries folder
//#define Language ES //Spanish
```
language is still ENG.

villamany, 2019-04-25:
I don,t know what is the exact error, maybe de POGMEM sentence not valid with compiler directives??? But if you cut and paste the lines of your language in the first place it will take effect

villamany, 2019-05-02:
Fixed https://github.com/augisbud/m365_dashboard/pull/55

LukCaha, 2019-05-03:
It works! Thanx!

Closed 2019-05-03.

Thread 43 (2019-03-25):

How do I use uno instead of pro mini?

diqmwl, 2019-03-25:
How do I use uno instead of pro mini?

Do I have to change resistors or diodes?

Rosch94, 2019-03-25:
no im currently programming with arduino mega. use the same schematis. I would also recommand u to use the mega. With the mega u can open 2 serial communication one for the m365 and one for live debugging

NetBUG, 2019-03-25:
Uno is almost equivalent to Pro Mini, in worst case you will need to detach Serial adapter circuitry because of combined wire hack used.
Mega or Leonardo will be more convenient because of two ports but it's not necessary.
Anyway the live device should be as small as possible, thus full-size Arduino boards seem strange for it.

I would suggest to use Pro Micro as it's a minified clone of Leonardo.

diqmwl, 2019-03-26:
Mega rx tx What number did you use?

0 is an error :(

augisbud, 2019-03-26:
well, you need to disable the serial programmer on the uno, then you can use it, there is a lot of possibilities to do that

Closed 2019-04-30.

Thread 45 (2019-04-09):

Power on through arduino

baldemir, 2019-04-09:
Hello,

I want to ask you if it is possible to switch on the scooter via arduino. In your project you have used arduino to get information about scooter. I want to learn if you have figured out a way to push some commands to scooter via arduino?

Thanks in advance

NetBUG, 2019-04-09:
In fact, all the information gathering is done by sending commands in a loop and listening to responses (see `defines.h`). There are even explicit commands to update KERS/light settings.
It is possible to sniff commands sent by controller to the bus to make the main controller power up everything.
However, there is no +5Vcc supply when the scooter is off, you will need a DC-DC converter to power it from +42 coming directly from the battery.

The connected panel indeed with current firmware indeed prevents to reflash the controller, as it spams out the bus, I've done a dirty "Pause communication" feature for that.

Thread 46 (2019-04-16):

Blinking LEDs on the scooter Board

lVlapuyc, 2019-04-16:
When you turn on the light, blink the LEDs on the circuit Board of the scooter. What could be the problem?

Rus: Когда включаю свет, мигают светодиоды на плате скутера. В чем может быть проблема?

Sasha1804, 2019-04-16:
Надо заменить предохранитель на контроллере самоката (F2). Можно поставить нулевой резистор

lVlapuyc, 2019-04-16:
Я умею пользоваться паяльником, НО я полный ноль в этих контроллерах, схемах и т.п. Могу только по инструкции делать. Если не сложно, можете как-то более подробно сказать, где его заменить? F2 для меня дремучий лес)
И еще вопрос, я напечатал корпус из ABS, и попробовал его посадить на бесцветный сантехнический герметик. Так вот, к металлу самоката герметик отлично прилип, а к abs вообще не липнет. На что приклеивать?

lVlapuyc, 2019-04-16:
Что такое нулевой резистор? Можете ссылку дать, к примеру, в чип и дип (chipdip), чтобы я точно знал что купить?

Sasha1804, 2019-04-16:
https://www.chipdip.ru/product0/9000079834 такой резистор. Либо, еще лучше, самовосстанавливающийся предохранитель (любой), но размер должен быть 1206!!!
Вот видео о замене: https://www.youtube.com/watch?v=ZleIXDNYiq4&feature=youtu.be

lVlapuyc, 2019-04-16:
Видео дает понять, как выпаять и как впаять. А где именно этот резистор находится на плате? Пжл, разжуйте мне более подробно, как для ламера, вы мой единственный русскоязычный помощник)

lVlapuyc, 2019-04-17:
Добрый вечер. Пара вопросов:
1. На видео используют предохранитель MF-NSMF050-2 BOURNS на 0,5А, номинальным напряжением 13,2В. Вы пишете, что подойдет любой, главное чтобы был 1206, непонятно, почему любой? Ведь другие могут быть рассчитаны на другие токи и напряжения, в таком случае теряется роль предохранителя.
2. На всякий случай поконкретней напишу, у меня мигают светодиоды на плате в руле и только тогда, когда свет включаю. Но, сегодня отпаял от этой платы назад все проводки от ардуино, и все мигание исчезло. Т.е. сам самокат и контроллер в порядке. Это точно проблема в предохранителе?

Я могу предположить, что предохранитель видимо там стоит тоже самовосстанавливающийся и рассчитанный на определенный ток, и когда я подключаю монитор с ардуино, они на себя берут часть мощности, которая соразмерна или меньше мощности фары. Но когда я еще и фару включаю, с контроллера начинает браться больше мощности, сила тока возрастает и срабатывает предохранитель. Если это так, то тем более любой не подойдет. Но, я очень далек от всех этих электронных вещей, поэтому это только мое предположение.

augisbud, 2019-05-07:
since I don't understand any of this and google translate isn't much help either, I'm closing it, but for anyone else having the same problem, you have to change out the f2 (fuse). Check out #37 for english instructions/discussion.

Closed 2019-05-07.

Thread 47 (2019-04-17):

Is it possible for the Pro Mini to *send* commands?

flienky, 2019-04-17:
Well, if I understand correctly, the Pro Mini only reads the commands that the other microcontrollers send.

Is it possible for the Pro Mini to send commands also, for example, to lock the scooter, or control the lights? Is there any problem with that approach?

Many thanks!

NetBUG, 2019-04-17:
As far as I understand, Mini Pro is a board with USB-Serial converter on board. Thus, the Tx pin of the ATMEGA chip sinks to converter and cannot provide enough power to drive the bus.
I would suggest to use other pins for bus interaction (e.g. pins 2-3 etc) and use SoftwareSerial instead of the Serial port.

Thus you change XIAOMI_PORT from Serial to SoftwareSerial in `defines.h` and use custom Rx and Tx pins when initializing it.

augisbud, 2019-04-18:
You can control the rear light, cruise control and the regenaration. :)
The arduino isn't stable enough for locking (it might freeze)

Closed 2019-04-18.

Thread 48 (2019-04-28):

Changing M365 firmware issue

villamany, 2019-04-28:
Any way for locking or hang the Arduino from the menu or at startup? I need to unpower the Arduino or disconnect the BUS wire for updating the firmware due the Arduino has the BUS bussy polling continuously data. I think a system for doing that would be very welcome without any need to add phisical switch or similar.

NetBUG, 2019-04-29:
I have done it in my branch: https://github.com/NetBUG/m365_dashboard/commit/f4529d95cd2296b94bd074f509d44b38e645f2fc
One thing is that I made a special PCB instead of tiny Arduino + dedicated screen, so the pin mapping for the display differs from the original one by @augisbud.

I have a button and an LED on the board, so the previous commit adds the code to handle button press.

villamany, 2019-04-29:
Nice, but what about to use a new menu item for that or maybe a booting test... IE: if arduino boots with the throttle pushed set the UART pins as inputs (hi impedance state) and goto sleep until next reboot?

villamany, 2019-04-29:
I have only basics of Arduino, but after first check the code, seems easy to implement. I will try to add that feature and post the result. If throttle > 150 at startup, dissable the UART and enter into infinite loop until next repowering.

villamany, 2019-04-29:
Done. Seems to works fine:
https://github.com/augisbud/m365_dashboard/pull/50

augisbud, 2019-04-30:
merged

afonsos, 2019-04-30:
Now that I have a switch?  :)
You guys are great,Thanks

Closed 2019-04-30.

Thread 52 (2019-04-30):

No data

rushtamas, 2019-04-30:
Hello,
I buld it and it says no data, and the screen flashing.
When I press the button on the arduino, rebooting continuously.
What could be the problem?

villamany, 2019-04-30:
Post a picture of your wiring and diode/resistor position

smidak, 2019-05-01:
I have the same problem. Pressing the adrduino reset button starts and does not function again when the power is cut off(no data)

NetBUG, 2019-05-01:
Hi guys,
this is 100% a hardware problem with the connection between the bus and controller.
Pressing any buttons won't work, since is does not change anything about the data.
If you use an ATMega32U8-based board - double-check the connection (diode and resistor) and ensure the value is correct (100-150 Ohm, not 150K! :) )
If you use a board with Mega328P - ensure that the pins are not puled down by the USB-TTL converter. If you have a board with that, it's advised to use SoftwareSerial on another pins (e.g. 2-3) rather than the hardware Serial.

villamany, 2019-05-01:
I'm using the diode and 220ohm resistor in TX line and another 220ohm resistor in RX line and working fine (i prefer to limit any current on both pins)

rushtamas, 2019-05-03:
I checked the diode polarity, the ohm resistance, tried with another board. Now "Bus not connected" screen shows, and can't turn off the M365 until I'm not plugging out the cables. But the screen not flickering, and not rebooting.

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

villamany, 2019-05-03:
Check the previous @NetBUG reply.
You are using a NANO board with USB, the USB-UART chip uses the same TX and RX pins that you are trying to use for the M365 communication. The standard assembly uses an Arduino MINI tbat doesn't have USB.

rushtamas, 2019-05-03:
Okay, thx! I'll try it with arduino without usb on monday!

villamany, 2019-05-03:
As described by @NetBUG you can use software serial port on other pins or simply cut the traces fom TX/RX pins to the USB chip and use bootloader with an FTDI device or ICSP method

smidak, 2019-05-03:
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

smidak, 2019-05-03:
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

augisbud, 2019-05-07:
is the diode and the resistor correct? @smidak

smidak, 2019-05-08:
Yes, 2x220ohm+ TX diode😭

Closed 2019-07-03.

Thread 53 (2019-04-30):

Temperature

afonsos, 2019-04-30:
Not really an issue as we can live with that :)
Does yours show temp higher than on android apps like tools for ex.? 10ºC difference.
Today it was displaying 40ºC connected tools and it was 28/30

augisbud, 2019-05-07:
The temperature you see in stationary isn't the battery temperature, it's the vehicle body temperature, you will see the battery temperature while charging. Here are some pics from my testing.
[Scooter Display](https://i.imgur.com/mxWCxUv.jpg)
[M365 Dashboard on Android](https://i.imgur.com/0EPj9uZ.jpg)
[M365 Tools on Android](https://i.imgur.com/NWnBVCL.jpg)

afonsos, 2019-05-07:
Thats right,my fault :)
Thanks augis

Closed 2019-05-07.

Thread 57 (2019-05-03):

Display ECO mode

LukCaha, 2019-05-03:
Is it possible to indicate ECO mode on the display?
I tried looking in the code but without success.

villamany, 2019-05-07:
Checking the file "defines.h" seems to be stored in "S21C00HZ64.state" var where //0-stall, 1-drive, 2-eco stall, 3-eco drive

augisbud, 2019-05-07:
unless you use a bigger display than 0.96" displaying the presence of eco mode is kinda useless since we still have the 4 notification leds, but @villamany is right

Closed 2019-05-07.

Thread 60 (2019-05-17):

3D case cads

kuzmanzs, 2019-05-17:
Hi,

I would like to ask you what is difference between Bracket-edited vs Bracket vs newCase?

villamany, 2019-05-17:
It is the same concept. I recommend to use the newCase. It is an improved version: https://github.com/augisbud/m365_dashboard/pull/49

Closed 2019-05-20.

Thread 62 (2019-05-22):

STL dimension problem

kuzmanzs, 2019-05-22:
Hi,

I have problem with size centimeter vs millimeter..
Could you upload cm version from bracket.stl?

jorgeuve, 2019-06-02:
I have published my desing for this project. Try it  if you like and of course I will add to this project if others contributors are agree.
https://www.thingiverse.com/thing:3646680

Closed 2019-07-03.

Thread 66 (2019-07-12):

Russian gibberish

tokfrans03, 2019-07-12:
Hello, ive been trying to get this working for a while now but it's not going too well.

I'm getting this on my I2C screen after starting [Image](https://i.imgur.com/nW5RPlj.jpg). And according to my russian friend its nothing but gibberish

I've imported all the LIB's and put em in the documents folder and followed all other instructions.

What can I do?

LukCaha, 2019-07-12:
Connect it with M365 ;-)

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

tokfrans03, 2019-07-13:
That shouldn't be necessary tho right?

NetBUG, 2019-07-13:
Hi guys!
I know the Russian localization looks weird. However, it works fine on the screen -- there is a feature of the fonts used. They do not follow neither UTF-8 convention (what a surprise for a bitmap font!), neither any of 8-bit encodings (ASCII, KOI etc). Unfortunately, the conversion is too complicated to be done on the go at compile-time through inlines -- or the macro would be huge.

If it's necessary, I can make a short code that converts from Unicode at runtime for these fonts, it will take about ~140 bytes of RAM. However, I'm surprised that the question was not raised by any Russian-speaking developer.
P.S. I do not know where to get additional fonts in case there is a request for Arabic/Hebrew/Norsk/Korean or any other languages support.

tokfrans03, 2019-07-15:
I just want it to work. I'm willing to help you out in any way possible

NetBUG, 2019-07-15:
Sorry, I didn't get your issue — I thought you're talking about unreadable strings in the code.

I have to check but the snapshot from early April must work correctly (language RU in language.h + System5x7mod.h as a font source — I tested it but reverted to English as it reads easier). The updates might have changed something.
I'll be by my scooter on Friday, so I can't check earlier, sorry

tokfrans03, 2019-07-15:
Oooo I think I fixed it! I just used the default "Adafruit5x7" font mentioned in some example code for the screen instead of "defaultfont". [Image](https://i.imgur.com/5XdflrQ.jpg)

thehair, 2019-08-09:
Just fyi for anyone else having this issue. I believe i was accidentally using the russian font and for some reason i couldn't get it to use the english font. I changed the following line in the defines.h from "#if Language == RU" to "#ifdef LANG_RU" and that fixed my issue

Closed 2019-07-15.

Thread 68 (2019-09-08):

black screen

jasiekxl, 2019-09-08:
I did everything like is wrote  and screen is black,

dimitrisdaniil, 2019-09-09:
You should probably check the first lines of the code where it chooses between spi and i2c protocolls
(correct me if i am wrong - newbie though -but i fix it this way)

satan671, 2019-09-10:
I had the same problem and by default is DISPLAY_SPI in file defines.h

dimitrisdaniil, 2019-09-11:
Yes thats it

Closed 2020-06-16.

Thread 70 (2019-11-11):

Getting a green led with blinking tail lights

duffann, 2019-11-11:
Hello,

I have a strange problem. I power the arduino uno directly from the battery with a dc-dc converter with 12v, common the grounds , and using 120r and 1n4148 to connect to arduinos rx and tx with databus. When I power on the scooter while the ardunio is already on, I get a green led indicator with blinking taillight. ( I assume the connection between the esc and ble is borken) , as soon as I remove the connection from rx and tx, everything is ok with the scooter.

I need to power the arduino from the main battery not from the ble.
What is wrong with my setup ?

Thanks

MathieuBre, 2019-11-13:
Hi,
The trouble you are experiencing is due to the voltage level on the arduino Uno on RX/TX pins. Indeed, the arduino Uno is forcing an average voltage higher than the bus which avoid the normal operation of the scooter (all data appear to be 0 if you check from the application). On an Arduino nano, this issue doesn't exist.

duffann, 2019-11-13:
> Hi,
> The trouble you are experiencing is due to the voltage level on the arduino Uno on RX/TX pins. Indeed, the arduino Uno is forcing an average voltage higher than the bus which avoid the normal operation of the scooter (all data appear to be 0 if you check from the application). On an Arduino nano, this issue doesn't exist.

What If I use only the microcontroller : Atmega328p isntead of the ardunio ?

MathieuBre, 2019-11-13:
the ATmega328p is the microcontroller of the Arduino nano, hence it should work properly. The "p" in this version stand for low power. Also, don't forget to add the diode/resistor on TX pin, and one resistor on RX pin (avoid to drain to much current).

duffann, 2019-11-13:
> the ATmega328p is the microcontroller of the Arduino nano, hence it should work properly. The "p" in this version stand for low power. Also, don't forget to add the diode/resistor on TX pin, and one resistor on RX pin (avoid to drain to much current).

Thanks for the answer, It is also the microcontroller of Ardunio uno but I dont think there will be a problem as you say. I am using the connection schematic in this github It only shows one resistor and diode on tx pin and nothing in rx, which resistor should I use for rx ?

MathieuBre, 2019-11-13:
Checking on the solved issues (https://github.com/augisbud/m365_dashboard/issues/52), it seems that a 220Ohm resistor should do it. I had the same issue as you using an Arduino Uno, switching to a Nano solved the communication trouble (at least the green led issue you are having).

duffann, 2019-11-13:
> Checking on the solved issues (#52), it seems that a 220Ohm resistor should do it. I had the same issue as you using an Arduino Uno, switching to a Nano solved the communication trouble (at least the green led issue you are having).

So I will try removing arduino uno and use its microcontroller only atmega328p and use 220ohm + diode on tx and 220ohm on rx.

duffann, 2019-11-13:
> Checking on the solved issues (#52), it seems that a 220Ohm resistor should do it. I had the same issue as you using an Arduino Uno, switching to a Nano solved the communication trouble (at least the green led issue you are having).

by the way , are you using 120 or 220 on nano ?

MathieuBre, 2019-11-13:
i used 120Ohm. if this is still not working for you, i suggest you use a SerialSoftware instead of the classical RX/TX pins.

duffann, 2019-11-13:
> i used 120Ohm. if this is still not working for you, i suggest you use a SerialSoftware instead of the classical RX/TX pins.

Thanks for all the answers it was a big help. Last question, if we switch to software serial, anything needs to change on the code side ? I couldnt find where we declared them.

MathieuBre, 2019-11-13:
You need to replace the line "#define XIAOMI_PORT Serial" from the defines.h file by:
`#include <SoftwareSerial.h>
SoftwareSerial XIAOMI_PORT(2, 3); // RX, TX`

Also it will free the classical serial for debugging.

duffann, 2019-11-13:
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

Perfect! Thanks very much. Will share the result tomorrow.

MaeseppTarvo, 2021-05-03:
@duffann I know it is an old thread but can you tell me did you manage to get it to work? It seems that all the data is moving but the software do not know what to do with it.
I tried to change the #define XIAOMI_PORT Serial with #include <SoftwareSerial.h> SoftwareSerial XIAOMI_PORT(2, 3); // RX, TX but it gives me an erros:

```
In file included from /Users/xistence/Desktop/m365_display-master/nano_just_speedometer/nano_just_speedometer.ino:1:0:
sketch/defines.h:15:29: warning: extra tokens at end of #include directive
 #include <SoftwareSerial.h> SoftwareSerial XIAOMI_PORT(2, 3); // RX, TX
                             ^~~~~~~~~~~~~~
/Users/xistence/Desktop/m365_display-master/nano_just_speedometer/nano_just_speedometer.ino: In function 'void setup()':
nano_just_speedometer:6:3: error: 'XIAOMI_PORT' was not declared in this scope
   XIAOMI_PORT.begin(115200);
   ^~~~~~~~~~~
/Users/xistence/Desktop/m365_display-master/nano_just_speedometer/nano_just_speedometer.ino: In function 'void dataFSM()':
nano_just_speedometer:205:13: error: 'XIAOMI_PORT' was not declared in this scope
       while(XIAOMI_PORT.available() >= 2){
             ^~~~~~~~~~~
nano_just_speedometer:236:13: error: 'XIAOMI_PORT' was not declared in this scope
       while(XIAOMI_PORT.available()){               //read available bytes from port-buffer
             ^~~~~~~~~~~
/Users/xistence/Desktop/m365_display-master/nano_just_speedometer/nano_just_speedometer.ino: In function 'void sendQueryFromTable(unsigned char)':
nano_just_speedometer:538:3: error: 'XIAOMI_PORT' was not declared in this scope
   XIAOMI_PORT.write((unsigned char*)&buf, DataLen + 2);     //DataLen + length of cs
   ^~~~~~~~~~~
exit status 1
'XIAOMI_PORT' was not declared in this scope
```

Closed 2020-06-16.

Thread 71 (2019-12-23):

Could that work on the Pro ?

PeterMikeSmooth, 2019-12-23:
Hello !

Thanks for that cool project !

Pro dashboard only has speed indicator. It would be great to have all these additional informations on the Pro.

However Pro bluetooth board runs on ble90 firmware. And classic on ble72 firmware.

Apparently the one-wire protocole is different on these two firmwares.

How hard would it be to make this project compatible with ble90 (i.e. Pro scooters) ?

Thank you !

PeterMikeSmooth, 2020-01-04:
Nobody ?

augisbud, 2020-06-16:
I don't think so, the firmware is different

Closed 2020-06-16.

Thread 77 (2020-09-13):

Language switching problem

38293312, 2020-09-13:
I choose the language == ENG in the source code M365.ino/defines.h. However, the RU language is still displayed when it is turned on. What is wrong?

LukCaha, 2020-09-13:
Choose the language in `language.h`

38293312, 2020-09-14:
> 选择语言 `language.h`

Thank you, English can now be displayed normally!

Closed 2020-10-19.

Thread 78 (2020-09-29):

Unable to use en language

Frog9920, 2020-09-29:
I unconnected the EN language from the language.h and Russian can’t be changed .

augisbud, 2020-09-29:
Can't talk now.
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

ArduinoTT, 2020-10-14:
Need write this

#include "fonts/m365.h"/*
#if LANG == RU
  #include "fonts/System5x7ru.h"
#else*/
  #include "fonts/System5x7mod.h"/*
#endif*/

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

and need uncomment your favorite language in language.h

Closed 2020-10-19.

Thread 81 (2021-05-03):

Change mode

ste-giordano95, 2021-05-03:
Any way to change mode from arduino? (eco, dynamic, sport) ?
Thank u!

augisbud, 2021-05-03:
Hello, not sure, since I haven't touched this in a log time. If you are familiar with coding projects like these I would suggest the best place to start would be
```
struct __attribute__ ((packed)) {
  uint8_t state;      //0-stall, 1-drive, 2-eco stall, 3-eco drive
  uint8_t ledBatt;    //battery status 0 - min, 7(or 8...) - max
  uint8_t headLamp;   //0-off, 0x64-on
  uint8_t beepAction;
} S21C00HZ64;
```

then you would need to find the correct command

```
enum {CMD_CRUISE_ON, CMD_CRUISE_OFF, CMD_LED_ON, CMD_LED_OFF, CMD_WEAK, CMD_MEDIUM, CMD_STRONG};
struct __attribute__((packed)) CMD{
  uint8_t  len;
  uint8_t  addr;
  uint8_t  rlen;
  uint8_t  param;
  int16_t  value;
}_cmd;
```

however from what I recall we didn't find the opportunity to toggle the headlight from an arduino.

Although the controller provides information about it's current mode I'm not sure if you will be able to change it.
If you have any luck feel free to submit a PR.

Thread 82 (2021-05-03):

Can not get data (tried on Micro and Leonard)

MaeseppTarvo, 2021-05-03:
Hey guys! Can someone lead me somewhere...

I am using exatcly the same components with same connection as mentioned everywhere: 1N4148 Diode, 0.25w 120ohm Resistor.

For me It seems that all the data is moving but the software do not know what to do with it(Arduino).
I tried to change the
`#define XIAOMI_PORT Serial` with/to `#include <SoftwareSerial.h> SoftwareSerial XIAOMI_PORT(2, 3);` but it gives me an erros:

`'XIAOMI_PORT' was not declared in this scope`

With multimeter I tested against ground that data exists and the TX output value was about 3.001v

augisbud, 2021-05-03:
Are you using the original M365?
What's your DRV version?

MaeseppTarvo, 2021-05-03:
@augisbud Yes, I am using original M365 the EU version with custom firmware. DRV is 155, BMS 126 and BLE 090. Thank you for your very quick response 🙂

augisbud, 2021-05-03:
I'm not sure where you should start, maybe try their code with the lcd, just change the lcd printing to Serial. I can't really guarantee it will work.
I have acquired the M365 Pro, I believe I still have all the hardware and I will try to hook everything up to test since I see this is still being used by people.

MaeseppTarvo, 2021-05-04:
@augisbud It is good to know that you have the ability to test it, it would be awesome to know if you as a project author would be able to get correct values.

Also wanted to mention that to try with minimal code I took [this](https://github.com/fogbox/m365_display/tree/master/nano_just_speedometer) repo but everything is actually same with yours. But changing `#define XIAOMI_PORT` Serial to `#define XIAOMI_PORT Serial1` gave me some numbers and communication started :) Also had to change `UCSR0B &= ~_BV(RXEN0);` to `UCSR0B &= ~_BV(RXEN0);` because otherwise you get an undefined/undeclared errors. Unfortunately I have no idea what difference it makes or why those changes needs to be done?

Dubstaaa, 2021-11-15:
Im sorry for my low level English... I made possible to read all values on pro 2, 1s, essential and 3 including speed value. everything works fine now!
visit my GitHub page, here's soon I will release the version v0.B

Dubstaaa, 2021-11-25:
Im glad to share with you my project, fully compatible with multiple scooter versions.
Neat dash, test release by Bruno. Available on https://github.com/Dubstaaa/NeatDash-

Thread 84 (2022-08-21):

No data when motor works

erdeidominik99, 2022-08-21:
Hello!
The code works fine, if I turn the wheel by hand the speed increases, but if I start the motor the data stops to come from serial, and if I stop the motor it works again. What can cause this? Interference?

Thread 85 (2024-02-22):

error during compilation

Catalin332, 2024-02-22:
greetings to all, when I want to check the code, this error appears
Arduino: 1.6.6 (Windows 10), Board: "Arduino Pro or Pro Mini, ATmega328P (3.3V, 8 MHz)"

avr-g++: error: missing filename after '-o'

exit status 1
Error compiling.

  This report would have more information with
  "Show verbose output during compilation"
  enabled in File > Preferences.

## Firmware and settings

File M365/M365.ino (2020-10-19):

#include "defines.h"

bool displayClear(byte ID = 1, bool force = false) {
  volatile static uint8_t oldID = 0;

  if ((oldID != ID) || force) {
    display.clear();
    oldID = ID;
    return true;
  } else return false;
}

void WDTint_() {
  if (WDTcounts > 2) {
    WDTcounts = 0;
    resetFunc();
  } else WDTcounts++;
}

void setup() {
  XIAOMI_PORT.begin(115200);

  uint8_t cfgID = EEPROM.read(0);
  if (cfgID == 128) {
    autoBig = EEPROM.read(1);
    warnBatteryPercent = EEPROM.read(2);
    bigMode = EEPROM.read(3);
    bigWarn = EEPROM.read(4);
    WheelSize = EEPROM.read(5);
    cfgCruise = EEPROM.read(6);
    cfgTailight = EEPROM.read(7);
    cfgKERS = EEPROM.read(8);
  } else {
    EEPROM.put(0, 128);
    EEPROM.put(1, autoBig);
    EEPROM.put(2, warnBatteryPercent);
    EEPROM.put(3, bigMode);
    EEPROM.put(4, bigWarn);
    EEPROM.put(5, WheelSize);
    EEPROM.put(6, cfgCruise);
    EEPROM.put(7, cfgTailight);
    EEPROM.put(8, cfgKERS);
  }

#ifdef DISPLAY_I2C
  Wire.begin();
  Wire.setClock(400000L);
  display.begin(&Adafruit128x64, 0x3C);
  //display.begin(&SH1106_128x64, 0x3C); // if you use 1.3" display
#endif
#ifdef DISPLAY_SPI
  display.begin(&Adafruit128x64, PIN_CS, PIN_DC, PIN_RST);
  //display.begin(&SH1106_128x64, PIN_CS, PIN_DC, PIN_RST); // if you use 1.3" display
#endif
  // Uncomment to invert the screen. Useful for better vision on the yellow / blue screens
  // display.displayRemap(true);
  display.setFont(m365);
  displayClear(0, true);
  display.setCursor(0, 0);
  display.print((char)0x20);
  display.setFont(defaultFont);

  uint32_t wait = millis() + 2000;
  while ((wait > millis()) || ((wait - 1000 > millis()) && (S25C31.current != 0) && (S25C31.voltage != 0) && (S25C31.remainPercent != 0))) {
    dataFSM();
    if (_Query.prepared == 0) prepareNextQuery();
    Message.Process();
  }

  if ((S25C31.current == 0) && (S25C31.voltage == 0) && (S25C31.remainPercent == 0)) {
    displayClear(1);
    display.set2X();
    display.setCursor(0, 0);
    display.println((const __FlashStringHelper *) noBUS1);
    display.println((const __FlashStringHelper *) noBUS2);
    display.println((const __FlashStringHelper *) noBUS3);
    display.println((const __FlashStringHelper *) noBUS4);
    display.set1X();
  } else displayClear(1);

  WDTcounts = 0;
  WatchDog::init(WDTint_, 500);
}

void loop() { //cycle time w\o data exchange ~8 us :)
  dataFSM();

  if (_Query.prepared == 0) prepareNextQuery();

  if (_NewDataFlag == 1) {
    _NewDataFlag = 0;
    displayFSM();
  }

  Message.Process();
  Message.ProcessBroadcast();

  WDTcounts=0;
}

void showBatt(int percent, bool blinkIt) {
  display.set1X();
  display.setFont(defaultFont);
  display.setCursor(0, 7);
  if (bigWarn || (warnBatteryPercent == 0) || (percent > warnBatteryPercent) || ((warnBatteryPercent != 0) && (millis() % 1000 < 500))) {
    display.print((char)0x81);
    for (int i = 0; i < 19; i++) {
      display.setCursor(5 + i * 5, 7);
      if (blinkIt && (millis() % 1000 < 500))
        display.print((char)0x83);
        else
        if (float(19) / 100 * percent > i)
          display.print((char)0x82);
          else
          display.print((char)0x83);
    }
    display.setCursor(99, 7);
    display.print((char)0x84);
    if (percent < 100) display.print(' ');
    if (percent < 10) display.print(' ');
    display.print(percent);
    display.print('\%');
  } else
  for (int i = 0; i < 34; i++) {
    display.setCursor(i * 5, 7);
    display.print(' ');
  }
}

void fsBattInfo() {
  displayClear(6);

  int16_t tmp_0, tmp_1;

  display.setCursor(0, 0);
  display.set1X();

  tmp_0 = abs(S25C31.voltage) / 100;         //voltage
  tmp_1 = abs(S25C31.voltage) % 100;

  if (tmp_0 < 10) display.print(' ');
  display.print(tmp_0);
  display.print('.');
  if (tmp_1 < 10) display.print('0');
  display.print(tmp_1);
  display.print((const __FlashStringHelper *) l_v);
  display.print(' ');

  tmp_0 = abs(S25C31.current) / 100;       //current
  tmp_1 = abs(S25C31.current) % 100;

  if (tmp_0 < 10) display.print(' ');
  display.print(tmp_0);
  display.print('.');
  if (tmp_1 < 10) display.print('0');
  display.print(tmp_1);
  display.print((const __FlashStringHelper *) l_a);
  display.print(' ');
  if (S25C31.remainCapacity < 1000) display.print(' ');
  if (S25C31.remainCapacity < 100) display.print(' ');
  if (S25C31.remainCapacity < 10) display.print(' ');
  display.print(S25C31.remainCapacity);
  display.print((const __FlashStringHelper *) l_mah);
  int temp;
  temp = S25C31.temp1 - 20;
  display.setCursor(9, 1);
  display.print((const __FlashStringHelper *) l_t);
  display.print("1: ");
  if (temp < 10) display.print(' ');
  display.print(temp);
  display.print((char)0x80);
  display.print("C");
  display.setCursor(74, 1);
  display.print((const __FlashStringHelper *) l_t);
  display.print("2: ");
  temp = S25C31.temp2 - 20;
  if (temp < 10) display.print(' ');
  display.print(temp);
  display.print((char)0x80);
  display.print("C");

  int16_t v;
  int16_t * ptr;
  int * ptr2;
  ptr = (int16_t*)&S25C40;
  ptr2 = ptr + 5;
  for (uint8_t i = 0; i < 5; i++) {
    display.setCursor(5, 2 + i);
    display.print(i);
    display.print(": ");
    v = *ptr / 1000;
    display.print(v);
    display.print('.');
    v = *ptr % 1000;
    if (v < 100) display.print('0');
    if (v < 10) display.print('0');
    display.print(v);
    display.print((const __FlashStringHelper *) l_v);

    display.setCursor(70, 2 + i);
    display.print(i + 5); 
    display.print(": ");
    v = *ptr2 / 1000;
    display.print(v);
    display.print('.');
    v = *ptr2 % 1000;
    if (v < 100) display.print('0');
    if (v < 10) display.print('0');
    display.print(v);
    display.print((const __FlashStringHelper *) l_v);

    ptr++;
    ptr2++;
  }
}

void displayFSM() {
  struct {
    uint16_t curh;
    uint16_t curl;
    uint16_t vh;
    uint16_t vl;
    uint32_t sph;
    uint16_t spl;
    uint16_t milh;
    uint16_t mill;
    uint16_t Min;
    uint16_t Sec;
    uint16_t temp;
  } m365_info;

  int brakeVal = -1;
  int throttleVal = -1;

  int tmp_0, tmp_1;
  long _speed;
  long c_speed; //current speed
  // CURRENT SPEED CALCULATE ALGORYTHM
  if (S23CB0.speed < -10000) {// If speed if more than 32.767 km/h (32767)
    c_speed = S23CB0.speed + 32768 + 32767; // calculate speed over 32.767 (hex 0x8000 and above) add 32768 and 32767 to conver to unsigned int
  } else {
    c_speed = abs(S23CB0.speed); }; //always + speed, even drive backwards ;)
  // 10 INCH WHEEL SIZE CALCULATE
  if (WheelSize) {
    _speed = (long) c_speed * 10 / 8.5; // 10" Whell
  } else {
    _speed = c_speed; //8,5" Whell
  };
 
  m365_info.sph = (uint32_t) abs(_speed) / 1000L; // speed (GOOD)
  m365_info.spl = (uint16_t) c_speed % 1000 / 100;
  #ifdef US_Version
     m365_info.sph = m365_info.sph/1.609;
     m365_info.spl = m365_info.spl/1.609;
  #endif
  m365_info.curh = abs(S25C31.current) / 100;       //current
  m365_info.curl = abs(S25C31.current) % 100;
  m365_info.vh = abs(S25C31.voltage) / 100;         //voltage
  m365_info.vl = abs(S25C31.voltage) % 100;

  if ((m365_info.sph > 1) && Settings) {
    ShowBattInfo = false;
    M365Settings = false;
    Settings = false;
  }

  if ((c_speed <= 200) || Settings) {
    if (S20C00HZ65.brake > 130)
    brakeVal = 1;
      else
      if (S20C00HZ65.brake < 50)
        brakeVal = -1;
        else
        brakeVal = 0;
    if (S20C00HZ65.throttle > 150)
      throttleVal = 1;
      else
      if (S20C00HZ65.throttle < 50)
        throttleVal = -1;
        else
        throttleVal = 0;

    if (((brakeVal == 1) && (throttleVal == 1) && !Settings) && ((oldBrakeVal != 1) || (oldThrottleVal != 1))) { // brake max + throttle max = menu on
      menuPos = 0;
      timer = millis() + LONG_PRESS;
      Settings = true;
    }

    if (M365Settings) {
      if ((throttleVal == 1) && (oldThrottleVal != 1) && (brakeVal == -1) && (oldBrakeVal == -1))                // brake min + throttle max = change menu value
      switch (sMenuPos) {
        case 0:
          cfgCruise = !cfgCruise;
	  EEPROM.put(6, cfgCruise);
          break;
        case 1:
          if (cfgCruise)
            prepareCommand(CMD_CRUISE_ON);
            else
            prepareCommand(CMD_CRUISE_OFF);
          break;
        case 2:
          cfgTailight = !cfgTailight;
	  EEPROM.put(7, cfgTailight);
          break;
        case 3:
          if (cfgTailight)
            prepareCommand(CMD_LED_ON);
            else
            prepareCommand(CMD_LED_OFF);
          break;
        case 4:
          switch (cfgKERS) {
            case 1:
              cfgKERS = 2;
	      EEPROM.put(8, cfgKERS);
              break;
            case 2:
              cfgKERS = 0;
	      EEPROM.put(8, cfgKERS);
              break;
            default: 
              cfgKERS = 1;
	      EEPROM.put(8, cfgKERS);
          }
          break;
        case 5:
          switch (cfgKERS) { 
            case 1:
              prepareCommand(CMD_MEDIUM);
              break;
            case 2:
              prepareCommand(CMD_STRONG);
              break;
            default: 
              prepareCommand(CMD_WEAK);
          }
          break;
        case 6:
          WheelSize = !WheelSize;
          EEPROM.put(5, WheelSize);
	  break;
        case 7:
          oldBrakeVal = brakeVal;
          oldThrottleVal = throttleVal;
          timer = millis() + LONG_PRESS;
          M365Settings = false;
          break;
      } else
      if ((brakeVal == 1) && (oldBrakeVal != 1) && (throttleVal == -1) && (oldThrottleVal == -1)) {               // brake max + throttle min = change menu position
        if (sMenuPos < 7)
          sMenuPos++;
          else
          sMenuPos = 0;
        timer = millis() + LONG_PRESS;
      }

      if (displayClear(7)) sMenuPos = 0;
      display.set1X();
      display.setCursor(0, 0);

      if (sMenuPos == 0)
        display.print((char)0x7E);
        else
        display.print(" ");

      display.print((const __FlashStringHelper *) M365CfgScr1);
      if (cfgCruise)
        display.print((const __FlashStringHelper *) l_On);
        else
        display.print((const __FlashStringHelper *) l_Off);

      display.setCursor(0, 1);

      if (sMenuPos == 1)
        display.print((char)0x7E);
        else
        display.print(" ");

      display.print((const __FlashStringHelper *) M365CfgScr2);

      display.setCursor(0, 2);

      if (sMenuPos == 2)
        display.print((char)0x7E);
        else
        display.print(" ");

      display.print((const __FlashStringHelper *) M365CfgScr3);
      if (cfgTailight)
        display.print((const __FlashStringHelper *) l_Yes);
        else
        display.print((const __FlashStringHelper *) l_No);

      display.setCursor(0, 3);

      if (sMenuPos == 3)
        display.print((char)0x7E);
        else
        display.print(" ");

      display.print((const __FlashStringHelper *) M365CfgScr4);

      display.setCursor(0, 4);

      if (sMenuPos == 4)
        display.print((char)0x7E);
        else
        display.print(" ");

      display.print((const __FlashStringHelper *) M365CfgScr5);
      switch (cfgKERS) {
        case 1:
          display.print((const __FlashStringHelper *) l_Medium);
          break;
        case 2:
          display.print((const __FlashStringHelper *) l_Strong);
          break;
        default:
          display.print((const __FlashStringHelper *) l_Weak);
          break;
      }

    display.setCursor(0, 5);

      if (sMenuPos == 5)
        display.print((char)0x7E);
        else
        display.print(" ");

      display.print((const __FlashStringHelper *) M365CfgScr6);

    display.setCursor(0, 6);
    
    if (sMenuPos == 6)
        display.print((char)0x7E);
        else
        display.print(" ");
  
      display.print((const __FlashStringHelper *) M365CfgScr7);
       if(WheelSize) {
          display.print((const __FlashStringHelper *) l_10inch);
     }else{
          display.print((const __FlashStringHelper *) l_85inch);
      }  
      //display.setCursor(0, 7);

      /*for (int i = 0; i < 25; i++) {
        display.setCursor(i * 5, 6);
        display.print('-');
      }*/

      display.setCursor(0, 7);
      
      if (sMenuPos == 7)
        display.print((char)0x7E);
        else
        display.print(" ");

      display.print((const __FlashStringHelper *) M365CfgScr8);

      oldBrakeVal = brakeVal;
      oldThrottleVal = throttleVal;
 
      return;
    } else
    if (ShowBattInfo) {
      if ((brakeVal == 1) && (oldBrakeVal != 1) && (throttleVal == -1) && (oldThrottleVal == -1)) {
        oldBrakeVal = brakeVal;
        oldThrottleVal = throttleVal;
        timer = millis() + LONG_PRESS;
        ShowBattInfo = false;
        return;
      }

      fsBattInfo();

      display.setCursor(0, 7);
      display.print((const __FlashStringHelper *) battScr);

      oldBrakeVal = brakeVal;
      oldThrottleVal = throttleVal;
 
      return;
    } else
    if (Settings) {
      if ((brakeVal == 1) && (oldBrakeVal == 1) && (throttleVal == -1) && (oldThrottleVal == -1) && (timer != 0))
        if (millis() > timer) {
          Settings = false;
          return;
        }

      if ((throttleVal == 1) && (oldThrottleVal != 1) && (brakeVal == -1) && (oldBrakeVal == -1))                // brake min + throttle max = change menu value
      switch (menuPos) {
        case 0:
          autoBig = !autoBig;
          break;
        case 1:
          switch (bigMode) {
            case 0:
              bigMode = 1;
              break;
            default:
              bigMode = 0;
          }
          break;
        case 2:
          switch (warnBatteryPercent) {
            case 0:
              warnBatteryPercent = 5;
              break;
            case 5:
              warnBatteryPercent = 10;
              break;
            case 10:
              warnBatteryPercent = 15;
              break;
            default:
              warnBatteryPercent = 0;
          }
          break;
        case 3:
          bigWarn = !bigWarn;
          break;
        case 4:
          ShowBattInfo = true;
          break;
        case 5:
          M365Settings = true;
          break;
        case 6:
          EEPROM.put(1, autoBig);
          EEPROM.put(2, warnBatteryPercent);
          EEPROM.put(3, bigMode);
          EEPROM.put(4, bigWarn);
          Settings = false;
          break;
      } else
      if ((brakeVal == 1) && (oldBrakeVal != 1) && (throttleVal == -1) && (oldThrottleVal == -1)) {               // brake max + throttle min = change menu position
        if (menuPos < 6)
          menuPos++;
          else
          menuPos = 0;
        timer = millis() + LONG_PRESS;
      }

      displayClear(2);

      display.set1X();
      display.setCursor(0, 0);

      if (menuPos == 0)
        display.print((char)0x7E);
        else
        display.print(" ");

      display.print((const __FlashStringHelper *) confScr1);
      if (autoBig)
        display.print((const __FlashStringHelper *) l_Yes);
        else
        display.print((const __FlashStringHelper *) l_No);

      display.setCursor(0, 1);

      if (menuPos == 1)
        display.print((char)0x7E);
        else
        display.print(" ");

      display.print((const __FlashStringHelper *) confScr2);
      switch (bigMode) {
        case 1:
          display.print((const __FlashStringHelper *) confScr2b);
          break;
        default:
          display.print((const __FlashStringHelper *) confScr2a);
      }

      display.setCursor(0, 2);

      if (menuPos == 2)
        display.print((char)0x7E);
        else
        display.print(" ");

      display.print((const __FlashStringHelper *) confScr3);
      switch (warnBatteryPercent) {
        case 5:
          display.print(" 5%");
          break;
        case 10:
          display.print("10%");
          break;
        case 15:
          display.print("15%");
          break;
        default:
          display.print((const __FlashStringHelper *) l_Off);
          break;
      }

      display.setCursor(0, 3);

      if (menuPos == 3)
        display.print((char)0x7E);
        else
        display.print(" ");

      display.print((const __FlashStringHelper *) confScr4);
      if (bigWarn)
        display.print((const __FlashStringHelper *) l_Yes);
        else
        display.print((const __FlashStringHelper *) l_No);

      display.setCursor(0, 4);

      if (menuPos == 4)
        display.print((char)0x7E);
        else
        display.print(" ");

      display.print((const __FlashStringHelper *) confScr5);

      display.setCursor(0, 5);

      if (menuPos == 5)
        display.print((char)0x7E);
        else
        display.print(" ");

      display.print((const __FlashStringHelper *) confScr6);

      display.setCursor(0, 6);

      for (uint8_t i = 0; i < 25; i++) {
        display.setCursor(i * 5, 6);
        display.print('-');
      }

      display.setCursor(0, 7);

      if (menuPos == 6)
        display.print((char)0x7E);
        else
        display.print(" ");

      display.print((const __FlashStringHelper *) confScr7);

      display.setCursor(0, 8);

      if (menuPos == 7)
        display.print((char)0x7E);
      else
        display.print(" ");

      oldBrakeVal = brakeVal;
      oldThrottleVal = throttleVal;
 
      return;
    } else
    if ((throttleVal == 1) && (oldThrottleVal != 1) && (brakeVal == -1) && (oldBrakeVal == -1)) {
      displayClear(3);

      display.set1X();
      display.setFont(defaultFont);
      display.setCursor(0, 0);
      display.print((const __FlashStringHelper *) infoScr1);
      display.print(':');
      display.setFont(stdNumb);
      display.setCursor(15, 1);
      tmp_0 = S23CB0.mileageTotal / 1000;
      tmp_1 = (S23CB0.mileageTotal % 1000) / 10;
      if (tmp_0 < 1000) display.print(' ');
      if (tmp_0 < 100) display.print(' ');
      if (tmp_0 < 10) display.print(' ');
      display.print(tmp_0);
      display.print('.');
      if (tmp_1 < 10) display.print('0');
      display.print(tmp_1);
      display.setFont(defaultFont);
      display.print((const __FlashStringHelper *) l_km);

      display.setCursor(0, 5);
      display.print((const __FlashStringHelper *) infoScr2);
      display.print(':');
      display.setFont(stdNumb);
      display.setCursor(15, 6);
      tmp_0 = S23C3A.powerOnTime / 60;
      tmp_1 = S23C3A.powerOnTime % 60;
      if (tmp_0 < 100) display.print(' '); 
      if (tmp_0 < 10) display.print(' ');
      display.print(tmp_0);
      display.print(':');
      if (tmp_1 < 10) display.print('0');
      display.print(tmp_1);

      return;
    }

    oldBrakeVal = brakeVal;
    oldThrottleVal = throttleVal;
  }

  if (bigWarn && (((warnBatteryPercent > 0) && (S25C31.remainPercent <= warnBatteryPercent)) && (millis() % 2000 < 700))) {
    if (displayClear(4)) {
      display.setFont(m365);
      display.setCursor(0, 0);
      display.print((char)0x21);
      display.setFont(defaultFont);
    }
  } else
    if ((m365_info.sph > 1) && (autoBig)) {
      displayClear(5);
      display.set1X();

      switch (bigMode) {
        case 1:
          display.setFont(bigNumb);
          tmp_0 = m365_info.curh / 10;
          tmp_1 = m365_info.curh % 10;
          display.setCursor(2, 0);
          if (tmp_0 > 0)
            display.print(tmp_0);
            else
            display.print((char)0x3B);
          display.setCursor(32, 0);
          display.print(tmp_1);
          tmp_0 = m365_info.curl / 10;
          tmp_1 = m365_info.curl % 10;
          display.setCursor(75, 0);
          display.print(tmp_0);
          display.setCursor(108, 0);
          display.setFont(stdNumb);
          display.print(tmp_1);
          display.setFont(defaultFont);
          if ((S25C31.current >= 0) || ((S25C31.current < 0) && (millis() % 1000 < 500))) {
            display.set2X();
            display.setCursor(108, 4);
            display.print((const __FlashStringHelper *) l_a);
          }
          display.set1X();
          display.setCursor(64, 5);
          display.print((char)0x85);
          break;
        default:
          display.setFont(bigNumb);
          tmp_0 = m365_info.sph / 10;
          tmp_1 = m365_info.sph % 10;
          display.setCursor(2, 0);
          if (tmp_0 > 0)
            display.print(tmp_0);
            else
            display.print((char)0x3B);
          display.setCursor(32, 0);
          display.print(tmp_1);
          display.setCursor(75, 0);
          display.print(m365_info.spl);
          display.setCursor(106, 0);
          display.print((char)0x3A);
          display.setFont(defaultFont);
          display.set1X();
          display.setCursor(64, 5);
          display.print((char)0x85);
      }
      showBatt(S25C31.remainPercent, S25C31.current < 0);
    } else {
      if ((S25C31.current < -100) && (c_speed <= 200)) {
        fsBattInfo();
      } else {
        displayClear(0);

        m365_info.milh = S23CB0.mileageCurrent / 100;   //mileage
        m365_info.mill = S23CB0.mileageCurrent % 100;
        m365_info.Min = S23C3A.ridingTime / 60;         //riding time
        m365_info.Sec = S23C3A.ridingTime % 60;
        m365_info.temp = S23CB0.mainframeTemp / 10;     //temperature
	#ifdef US_Version
          m365_info.milh = m365_info.milh/1.609;
          m365_info.mill = m365_info.mill/1.609;
          m365_info.temp = m365_info.temp*9/5+32;
  #endif
        display.set1X();
        display.setFont(stdNumb);
        display.setCursor(0, 0);

        if (m365_info.sph < 10) display.print(' ');
        display.print(m365_info.sph);
        display.print('.');
        display.print(m365_info.spl);
        display.setFont(defaultFont);
        display.print((const __FlashStringHelper *) l_kmh);
        display.setFont(stdNumb);

        display.setCursor(95, 0);
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

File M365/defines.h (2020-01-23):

#include "WatchDog.h"

// Select either SPI or I2C(Wire) Display Mode
#define DISPLAY_SPI
//#define DISPLAY_I2C

//#define US_Version

#include "SSD1306Ascii.h"
#ifdef DISPLAY_SPI
  #include <SPI.h>
  #include "SSD1306AsciiSpi.h"
  #define PIN_CS  10
  #define PIN_RST 9
  #define PIN_DC  8
  #define PIN_D0 13
  #define PIN_D1 11
#endif
#ifdef DISPLAY_I2C
  #include "SSD1306AsciiWire.h"
#endif
#include "fonts/m365.h"
#if Language == RU
  #include "fonts/System5x7ru.h"
#else
  #include "fonts/System5x7mod.h"
#endif
#include "fonts/stdNumb.h"
#include "fonts/bigNumb.h"

#include <EEPROM.h>

#include "language.h"
#include "messages.h" 

MessagesClass Message;

const uint16_t LONG_PRESS = 2000;
uint8_t warnBatteryPercent = 5;

bool autoBig = true;
uint8_t bigMode = 0;
bool bigWarn = true;

bool Settings = false;
bool ShowBattInfo = false;
bool M365Settings = false;

uint8_t menuPos = 0;
uint8_t sMenuPos = 0;

bool cfgCruise = false;
bool cfgTailight = false;
uint8_t cfgKERS = 0;

volatile int16_t oldBrakeVal = -1;
volatile int16_t oldThrottleVal = -1;
volatile bool btnPressed = false;
bool bAlarm = false;

uint32_t timer = 0; 

#ifdef DISPLAY_SPI
SSD1306AsciiSpi display;
#endif
#ifdef DISPLAY_I2C
SSD1306AsciiWire display;
#endif

bool WheelSize = true; //whell 8,5"

uint8_t WDTcounts = 0;
void(* resetFunc) (void) = 0;

// -----------------------------------------------------------------------------------------------------------

#define XIAOMI_PORT Serial
#define RX_DISABLE UCSR0B &= ~_BV(RXEN0);
#define RX_ENABLE  UCSR0B |=  _BV(RXEN0);

struct {
  uint8_t prepared; //1 if prepared, 0 after writing
  uint8_t DataLen;  //lenght of data to write
  uint8_t buf[16];  //buffer
  uint16_t  cs;       //cs of data into buffer
  uint8_t _dynQueries[5];
  uint8_t _dynSize = 0;
} _Query;

volatile uint8_t _NewDataFlag = 0; //assign '1' for renew display once
volatile bool _Hibernate = false;   //disable requests. For flashind or other things

enum {CMD_CRUISE_ON, CMD_CRUISE_OFF, CMD_LED_ON, CMD_LED_OFF, CMD_WEAK, CMD_MEDIUM, CMD_STRONG};
struct __attribute__((packed)) CMD{
  uint8_t  len;
  uint8_t  addr;
  uint8_t  rlen;
  uint8_t  param;
  int16_t  value;
}_cmd;

const uint8_t _commandsWeWillSend[] = {1, 8, 10}; //insert INDEXES of commands, wich will be send in a circle

        // INDEX                     //0     1     2     3     4     5     6     7     8     9    10    11    12    13    14
const uint8_t _q[] PROGMEM = {0x3B, 0x31, 0x20, 0x1B, 0x10, 0x1A, 0x69, 0x3E, 0xB0, 0x23, 0x3A, 0x7B, 0x7C, 0x7D, 0x40}; //commands
const uint8_t _l[] PROGMEM = {   2,   10,    6,    4,   18,   12,    2,    2,   32,    6,    4,    2,    2,    2,   30}; //expected answer length of command
const uint8_t _f[] PROGMEM = {   1,    1,    1,    1,    1,    2,    2,    2,    2,    2,    2,    2,    2,    2,    1}; //format of packet

//wrappers for known commands
const uint8_t _h0[]    PROGMEM = {0x55, 0xAA};
const uint8_t _h1[]    PROGMEM = {0x03, 0x22, 0x01};
const uint8_t _h2[]    PROGMEM = {0x06, 0x20, 0x61};
const uint8_t _hc[]    PROGMEM = {0x04, 0x20, 0x03}; //head of control commands

struct __attribute__ ((packed)){ //dynamic end of long queries
  uint8_t hz; //unknown
  uint8_t th; //current throttle value
  uint8_t br; //current brake value
}_end20t;

const uint8_t RECV_TIMEOUT =  5;
const uint8_t RECV_BUFLEN  = 64;

struct __attribute__((packed)) ANSWER_HEADER{ //header of receiving answer
  uint8_t len;
  uint8_t addr;
  uint8_t hz;
  uint8_t cmd;
} AnswerHeader;

struct __attribute__ ((packed)) {
  uint8_t state;      //0-stall, 1-drive, 2-eco stall, 3-eco drive
  uint8_t ledBatt;    //battery status 0 - min, 7(or 8...) - max
  uint8_t headLamp;   //0-off, 0x64-on
  uint8_t beepAction;
} S21C00HZ64;

struct __attribute__((packed))A20C00HZ65 {
  uint8_t hz1;
  uint8_t throttle; //throttle
  uint8_t brake;    //brake
  uint8_t hz2;
  uint8_t hz3;
} S20C00HZ65;

struct __attribute__((packed))A25C31 {
  uint16_t  remainCapacity;     //remaining capacity mAh
  uint8_t   remainPercent;      //charge in percent
  uint8_t   u4;                 //battery status??? (unknown)
  int16_t           current;            //current        /100 = A
  int16_t           voltage;            //batt voltage   /100 = V
  uint8_t   temp1;              //-=20
  uint8_t   temp2;              //-=20
} S25C31;

struct __attribute__((packed))A25C40 {
  int16_t c1; //cell1 /1000
  int16_t c2; //cell2
  int16_t c3; //etc.
  int16_t c4;
  int16_t c5;
  int16_t c6;
  int16_t c7;
  int16_t c8;
  int16_t c9;
  int16_t c10;
  int16_t c11;
  int16_t c12;
  int16_t c13;
  int16_t c14;
  int16_t c15;
} S25C40;

struct __attribute__((packed))A23C3E {
  int16_t i1;                           //mainframe temp
} S23C3E;
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

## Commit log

2018-07-11 Added initial files
    [m365.dxf, m365v1.stl, m365v2.stl]
2018-08-24 Refreshed code
    Add a new modified version of the code and extra libraries.
    [m365.dxf, m365v1.stl, m365v2.stl]
2018-08-24 Added 3d files
    [Bracket.stl, LEDS & Button Extender.stl]
2018-09-22 add selectable SPI mode for OLED
    uncomment your #defines as needed
2018-09-29 added custom wheel size
2018-09-29 wheel size patch
2018-10-05 3D Files by Саша
    [Bracket-edited.stl, Connector-edited.stl]
2018-10-07 wheel size patch 2
2018-10-07 wheel size patch 2*
2018-10-10 fix inital EEPROM read bug
    [M365.ino]
2018-10-14 testing to see if we can display - current
    Testing to see if we can show when we're charging and discharging next to the ampers a.k.a current
2018-10-19 fixed saving wheelspeed
2018-10-19 fixed WhellSize name ;) and saving menu state
    fix WhellSize name ;)
    fixed saving and simpler menu
    round is not necessary, (unsigned int) does the same.
    [M365.ino]
2018-10-20 Update defines.h
    fixed "wheel"
    [defines.h]
2018-10-28 .
    wheel size not working right now, stick to other versions ;)
    testing for freezing
    [M365.ino]
2018-10-30 I correct the variables to "long" and changed assignments (unsigned long)
    [M365.ino]
2018-12-06 fix for Arduino 1.8.5
    [M365.ino]
2019-03-30 Circuit by Xek and slimline panel
    [Custom top panel.f3d, M365_panel_windowed.f3d]
2019-04-01 Remap for Xek's board
2019-04-01 Debugging button & LED
2019-04-29 Easier to print and assembling case
    No external support needs. Parts are self-supported. Source files included
    [carcasa_v3_wirhouSupports.STL, case_v3.SLDPRT, case_v3.STEP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]
2019-04-29 Stop interaction after button press, useful for firmware upgrade
2019-04-29 Dashboard disable mode for updating M365 firmware
    If you power on the scooter with the brake and throttle engaged, the dashboard is disabled and the TX/RX pins go to hi impedance state.
    By this way you can update de M365 firmware without disconnecting the dashboard.
2019-04-29 Dashboard disable mode for updating M365 firmware
    A new power cycle reset this status.
    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
    [M365.ino]
2019-04-30 Revert "Dashboard disable mode for updating M365 firmware"
    [M365.ino]
2019-05-02 Fixed the language selection in "language.h file"
    [M365.ino]
2019-06-18 Invert display orientation
    Line to invert the screen. Useful for better vision on the yellow / blue screens. Commented by default
    [M365.ino]
2019-07-15 added case for 1.3" screensizes based on villamany's design
    [case_v4_1.3-screen.f3d, case_v4_1.3-screen.step, case_v4_1.3-screen.stl]
2019-07-16 added 3d files and a readme
    [case_v4_1.3-screen.f3d, case_v4_1.3-screen.step, case_v4_1.3-screen.stl]
2020-01-19 Fix navigating in main menu.
    [defines.h]
2020-06-21 Italian language 🇮🇹
2020-10-14 Update M365.ino
    my update solved problem with 1.3" display, white line on the left and some letters can be consmed by the left side like
    https://i.imgur.com/5XdflrQ.jpg
    [M365.ino]
